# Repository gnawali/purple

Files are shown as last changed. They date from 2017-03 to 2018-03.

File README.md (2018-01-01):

# What is this repository for #

This repository contains hardware and software for building practical Visible Light Communication system. The PURPLE board is a cape that works with BeagleBone Black embedded computer. With PURPLE, one can send and receive information using visible light.

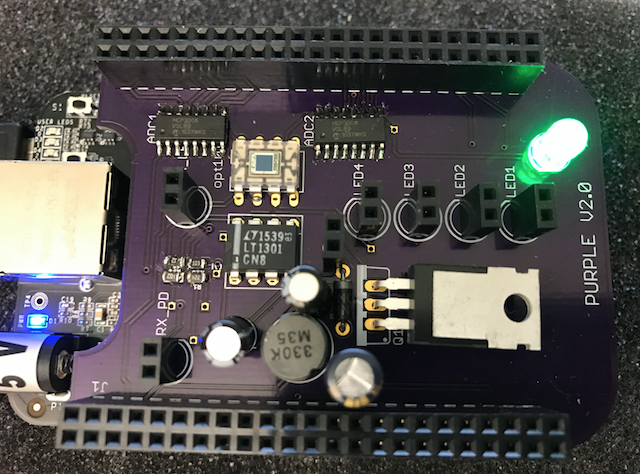
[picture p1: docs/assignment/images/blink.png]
blink


The hardware design is available in the eagle folder.

### What's included ###
* Firmware running on PRU including both transmitter and receiver
* User-space program to run on embedded Linux environment 
* Hardware schematic
* Partlist to assemble your own cape [Digi-Key](http://www.digikey.com/short/qq17qj)
* PCB ordering [OSH Park](https://oshpark.com/shared_projects/B5KA0qL4)

### Contents ###

* config/

 This directory contains all configuration files used before make.

* docs/

 This directory contains all documents and notes used as instructions and tutorials deployed in class.

* example/

 This directory contains the userspace program to send and receive msgs through light.

* firmware/

 This directory contains the binary files that's going to run on PRU

* pcb/

 This directory contains the hardware schematic and the PCB layout as well as the partlists.

* src/

 This directory contains the source file that needs to be compiled into the binary file under firmware folder.

* test/

 This directory contains the test and debugging file in user space for the PRU source code.

### How do I get set up? ###

- Summary of set up
    1. Hardware
    	- Beaglebone Black
    	- Purple Cape
    	- SD card
    	- Micro USB cable
    2. Software
	    - BBB Driver[[Windows]](https://learn.adafruit.com/ssh-to-beaglebone-black-over-usb/installing-drivers-windows)[[Mac]](https://learn.adafruit.com/ssh-to-beaglebone-black-over-usb/installing-drivers-mac)[[Linux]](https://learn.adafruit.com/ssh-to-beaglebone-black-over-usb/installing-drivers-linux)
	    - SSH[[Windows]](https://learn.adafruit.com/ssh-to-beaglebone-black-over-usb/ssh-with-windows-and-putty)[[Mac/Linux]](https://learn.adafruit.com/ssh-to-beaglebone-black-over-usb/ssh-on-mac-and-linux) 
    3. Internet Connection (optional)
	    - Ethernet Cable (Required physical access to the LAN port of your router/access point)
	    - [Wireless Dongle](https://learn.adafruit.com/setting-up-wifi-with-beaglebone-black/overview)
    
* Configuration
* Dependencies
* Deployment instructions
  1. LED installation.
  2. Photodiode installation.

### How to get started ###

Step 1: Insert SD card to BBB board. Make sure SD card has been flashed with the purple image.

Step 2: Boot Up the BBB board and connect the board to your PC/Laptop. Make sure you have successfully installed the drivers for BBB.

Step 3: SSH to the board. ssh debian@192.168.7.2

```
ssh debian@192.168.7.2
```
Step 4: When you login, Change to root.

```
sudo -s
```

Step 5: Go to purple repository.

```
cd purple
```

Step 6: Reload the pru remoteproc kernel module.

```
rmmod pru_rproc

modprobe pru_rproc

```

Step 7: Compile the code.
```
make clean
make
```
Step 8: Make sure the code got compiled succesfully.

Step 9: Start listening on incoming messages on one purple board.
```
cd example
./receive
```

Step 10: Start sending the messages on other purple board.
```
cd example
./send "hello world"
```

Step 11: Make sure the message got received correctly.

Step 12: Congratulations. You've completed this short tutorial.

### Who do I talk to? ###

* Shengrong Yin (syin@uh.edu) 
* Omprakash Gnawali (gnawali@cs.uh.edu) 

### References ###

[Exploring Beaglebone](http://exploringbeaglebone.com/chapter13/)

[PRU-ICSS](http://processors.wiki.ti.com/index.php/PRU-ICSS)

[PRU-software-support-package](https://git.ti.com/pru-software-support-package)

[spruhv7a](http://www.ti.com/lit/ug/spruhv7a/spruhv7a.pdf)

[arduino VLC](https://github.com/jpiat/arduino)

[PRU mailing list](https://groups.google.com/forum/#!forum/beagleboard)

[BeagleScope](https://github.com/ZeekHuge/BeagleScope)

[PRUDAQ](https://github.com/google/prudaq/wiki)

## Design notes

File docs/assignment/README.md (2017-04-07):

# OpenVLC 1.0 Get Started
This is to introduce the embedded visible light communication system based on BeagleBone Black (Rev. C) [BBB](http://beagleboard.org/project/OpenVLC/). 

## What do you need to get started
* 2 x [BBB Rev.C ](https://beagleboard.org/black) 
* 2 x [OpenVLC Cape](http://nsl.cs.uh.edu/~syin/openvlc/cape1.png)
* 2 x [mini USB cable](http://nsl.cs.uh.edu/~syin/openvlc/miniUSB.jpg)
* 2 x [LED (Type 1)](http://www.vishay.com/docs/83178/tlcr5800.pdf)
* 2 x [LED (Type 2)]
* 2 x [Power Supply](http://elinux.org/images/7/72/DC_Supply.jpg).

## Hardware Assembly
1. Attach the cape on top of BBB.
2. Attach LED on the pinout of the cape. See the [instructions](http://nsl.cs.uh.edu/~syin/openvlc/led_installation.pdf)
3. Power up the board.
4. Connect the mini USB cable to your PC/Desktop USB port.

## Software Preparation
1. Installing the image:
   * **OpenVLC image**: 
   * Download the [image](https://drive.google.com/file/d/0BwGT2J3dvAfNOEVibS1KQ2d5MGc/view)
   * Install the image on a SD card. You can following the [Raspberry Pi example](https://www.raspberrypi.org/documentation/installation/installing-images/)
   * Insert the SD card to BBB and boot the OS.
   * Install the [header file](https://drive.google.com/file/d/0BwGT2J3dvAfNcVljMTFUU2phQmc/view?usp=sharing) on BBB.
     For this, you can ssh to the board
`ssh machinekit@192.168.7.2` and type
`dpkg -i linux-headers-3.8.13xenomai-bone53_1.0cross_armhf.deb`
   * Download the openvlc source code and compile it.
2. Check on your PC/Desktop to see whether you have USB connections after you assembled all hardware.
   * **For Mac Users**: Type `option` + `space` key in your keyboard to open network preference, you will observe all operating connections. Click on the BeagleBone Black connection to see the IP address. Normally, this would be `192.168.7.1`. Once you confirmed with IP, you can connect to the board via SSH. 
   * **For Linux Users**: Open Terminal, and type `ifconfig` to see available network connections. You will observe the 
USB connection with IP address of `192.168.7.1`. Connect to the board via SSH.
   * **For Windows Users**:  First, you need to install the BeagleBone [USB drivers](http://beagleboard.org/static/Drivers/Windows/BONE_D64.exe) for windows. Before you do that, you have to disable driver signature verification on 64-Bit Windows 8 or 10 so that you can install the USB driver which is unsigned. To disable driver signature verification, please follow option 2 in this [link](http://www.howtogeek.com/167723/how-to-disable-driver-signature-verification-on-64-bit-windows-8.1-so-that-you-can-install-unsigned-drivers/). Once you install the USB driver successfully, you can open `Command Line Tools` and type `ipconfig`. You will notice a IP which is `192.168.7.1` from
the result. This shows the USB driver is successfully installed. 
Second, download [Putty](http://www.chiark.greenend.org.uk/~sgtatham/putty/download.html) and connect from Windows to the BeagleBone board using Putty. 

## Connecting to the BeagleBone Board (SSH)
   * **For Mac and Linux Users**: By default, the OS should already have SSH installed. So you can open terminal and type the following command  `ssh machinekit@192.168.7.2`. The default password is `machinekit`.
   * **For Windows Users**: You need to configure Putty using the IP address `192.168.7.2`. You can following this [tutorial](https://mediatemple.net/community/products/dv/204404604/using-ssh-in-putty-) to configure the SSH connection in Putty.

## Data Transmission Configuration.
Once you are able to access to the BBB via SSH.  

`sudo -s #change to root`   
`cd openvlc1.0 # go to the folder`  
`./bat_client.sh # insert the openvlc kernel module and configure it to be TX`  
`./ipert_client.sh # run iperf tool to start transmitting data throught the visible light channel`  

## Data Reception Configuration.
Once you are able to access to the BBB via SSH.  
`sudo -s # change to root`  
`cd openvlc1.0 # go to the folder`  
`./bat_server.sh # insert the openvlc kernel module and configure it to be RX`
`./iperf_server.sh # run iperf tool to start receiving data throught the visible light channel`

## Visible Light Communication Verification
From the iperf server terminal, you will observe the following measurement result.

As we can see from the iperf measurement result, the visible light communication link is established so that
we can observe the loss ratio and the round-trip time estimation (RTT).

Still so excited, let's start to work on some tasks that can help you learn how the system is implemented and what improvements we can help to contribute.

# Homework 1 (How to compile C file in Embedded Linux Environment)

- Objective:  
  - You will learn how to compile a file in Linux Environment.
  - You will learn how to use networking tools in Linux Environment, such as iperf, nc e.t.c.

- Instructions:  
   - In openVLC 1.0, we have provided an example file for you to get started, you can type the following command
to go to the example folder, which is `openvlc1.0`.  
`cd openvlc1.0`  
Here, you will find the source files that are used to create the kernel module. Normally, the kernel module has
a filetype that is `***.ko`. And you can load this module into the kernel to drive the VLC transceivers. 
It is similar when you plug in a WIFI USB dongle. Kernel driver for this particular WIFI USB dongle will load firmware 
into the MCU of the device and the USB device will start to transmit or receive data. Here, the VLC transceivers was 
managed by only the kernel module with no firmware running on external MCU.
To compile the source file into the kernel module, you just need to type  
`make`   
Linux will automatically compile the source file into the vlc.ko.  
Once you have the `vlc.ko` module, you need to load it into kernel. We wrote the script -`bat_client.sh` to help you load 
ther kernel with default configurations. But currently, the system is half-duplex meaning you have to configure the transceiver as either TX or RX. Let's assume we configure the first device as TX, we need to type  
`./bat_client.sh`.  
Now we are able to send data using the VLC transceiver that has been configured as the TX by typing  
`iperf_client.sh`  
You will observe the LED blinking as the indication for data transmission.  
   - In this homework, you need to repeat the procedure from the descriptions and submit a screenshot with the data analytics you received from the iperf server result.  

# Homework 2 (How to write a new modulation/demodulation for openVLC)
- Objective:
   - You will learn how data was transmitted from a human readable message to the binary code that are sent in physical layer. 
   - You will learn Linux Kernel Programming by modifying the kernel source file.
   - You will learn basic modulation and demodulation techniques for data communication.
- Instructions:  
   - We have provided you a C file and a Makefile to help you get started. Check this [repository](https://github.com/yinshengrong/vlc_lab1) to be prepared with the tasks. This lab will help you understand the basic 
kernel programming techniques. It is sending a fixed number of bytes from Kernel by controlling the blinking frequency of
the LED. It is modulating bit ONE and ZERO with different frequency. The frequency for bit ONE is 3 kHz, bit ZERO is 1.5 kHz. By blinking the LED using these two frequencies, the Binary Frequency Shift Keying Modulation is established.  
   - In this homework, you need to modify this BFSK modulation into an [On and Off Keying Modulation with Manchester Coding](https://en.wikipedia.org/wiki/On-off_keying). You should be able to modulate bit ZERO using the HIGH-LOW trigger and modulate bit ONE using the LOW-HIGH trigger or vice versa. 

# Homework 3 (Wireshark)

# Homework 4 (Socket programming on VLC)

# Homework 5 (ARM and PRU assembly)

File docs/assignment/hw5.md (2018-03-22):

# Blink LED with Programmable Realtime Unit 
This is to introduce the embedded visible light communication system based on BeagleBone Black (Rev. C). 

## What do you need to get started
* 2 x [BBB Rev.C ](https://beagleboard.org/black) 
* 2 x [Purple VLC Cape](https://github.com/gnawali/purple/blob/master/docs/assignment/images/blink.png)
* 2 x [mini USB cable](http://nsl.cs.uh.edu/~syin/openvlc/miniUSB.jpg)
* 2 x [LED (Type 1)](http://www.vishay.com/docs/83178/tlcr5800.pdf)

## Hardware Assembly
1. Attach the cape on top of BBB.
2. Attach LED on the pinout of the cape. See the [instructions](http://nsl.cs.uh.edu/~syin/openvlc/led_installation.pdf)
3. Power up the board.
4. Connect the mini USB cable to your PC/Desktop USB port.

## Software Preparation
1. Installing the image:
   - **Purple image**: 
   - Download the [image](https://debian.beagleboard.org/images/bone-debian-8.6-lxqt-4gb-armhf-2016-11-06-4gb.img.xz)
   * After downloading the image, you need 7-zip to extract the img file. You can first download [7-zip](http://www.7-zip.org/download.html). Then right click on the image file with the 7zip option to extract here.
   * Install the image (.img file) on a micro SD card. You can following the [Raspberry Pi example](https://www.raspberrypi.org/documentation/installation/installing-images/). If you are using Windows, you can download [Etcher](https://etcher.io/) and install the application, and write the .img file to SD card. You may need a [USB-to-microSD adaptor](https://www.amazon.com/Sabrent-SuperSpeed-Windows-Certain-Android/dp/B00OJ5WBUE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) if the computer you are using does not have the SD card slot. It will approximately take 10-20 minutes to write the image to your microSD card depending on the speed of the CPU that is running on your computer.
   * Insert the SD card to BBB and plug in BBB board on your computer via the provided USB cable.
   * If the OS running on your computer in Windows 10, you need to get a BBB driver for signed signature to be installed on your windows. You can download [this one](http://www.1-2-3-4-5-6.net/beaglebone/black/BONE_D64_signed.zip).
   * Download [Putty](http://www.chiark.greenend.org.uk/~sgtatham/putty/download.html) and connect from Windows to the BeagleBone board using Putty. 
   * Connect to the BBB board via ssh.
     `ssh debian@192.168.7.2`
   * After you logged in to the board, you can following [this link](http://elinux.org/EBC_Exercise_30_PRU_via_remoteproc_and_RPMsg) to load PRU kernel modules. To sum up, it is really important for you to follow the sequence.
   * In order to make things easier, we type all commands using root. To change the user to root, simply type the following command in a
   terminal.
   
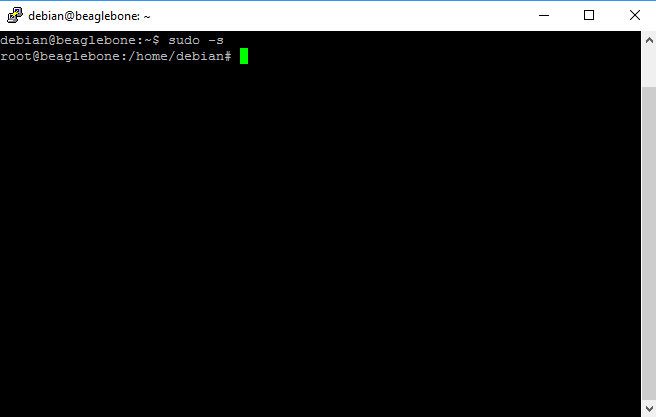
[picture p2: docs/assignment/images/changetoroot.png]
teminal<

   ```
   sudo -s
   ```
2. Enabling PRU module via Remoteproc framework:
   * **Check version**: we need to make sure the board version is larger than 4.4.12-ti-r32 or the following instructions will be   invalid.
   
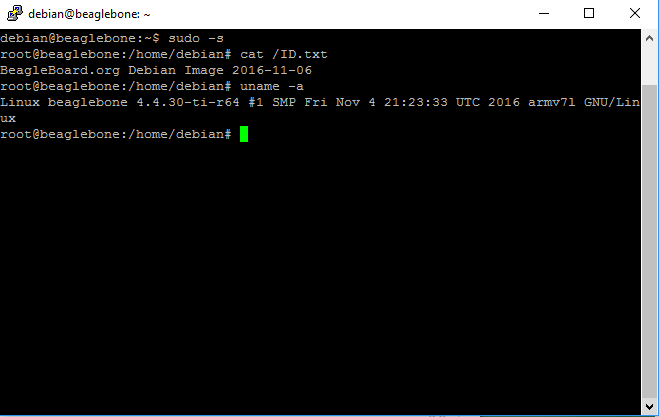
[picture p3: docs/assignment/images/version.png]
version<

   ```
   cat ./ID.txt
   uname -a
   ```
   * **Disable the HDMI**: The BBB provide multiplexing for the GPIOs, both PRU and HDMI will share the same GPIOs, so we have to disable the HDMI before we enable the PRU. How do we know whether the HDMI is disabled:
   
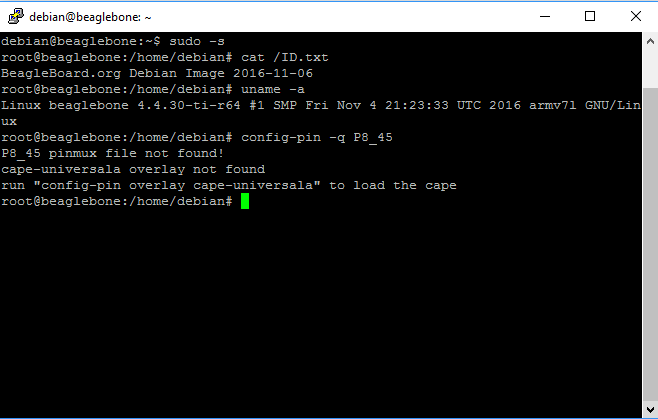
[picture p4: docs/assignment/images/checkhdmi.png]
checkHDMI<

   ```
   config-pin -q P8_45
   ```
   If the message was shown up in the terminal, we need to disable the HDMI. Open the `/boot/uEnv.txt`.
   
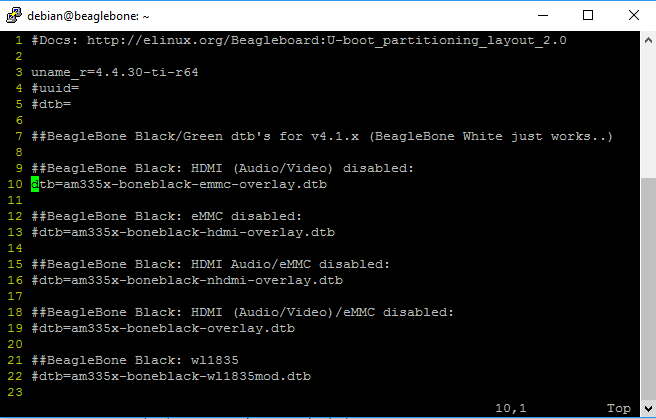
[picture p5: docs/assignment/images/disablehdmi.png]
disableHDMI<

   ```
   nano /boot/uEnv.txt
   ```
   After uncommenting # in line number 10, we save the file and reboot.
   
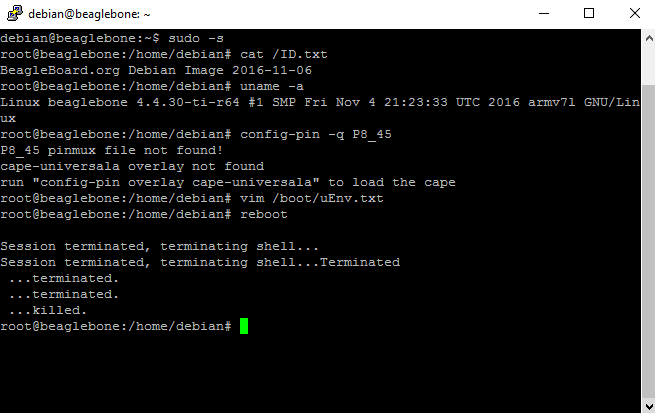
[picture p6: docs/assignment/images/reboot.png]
root<

   ```
   reboot
   ```
   Logging into the board again and check whether hdmi is disable:
   
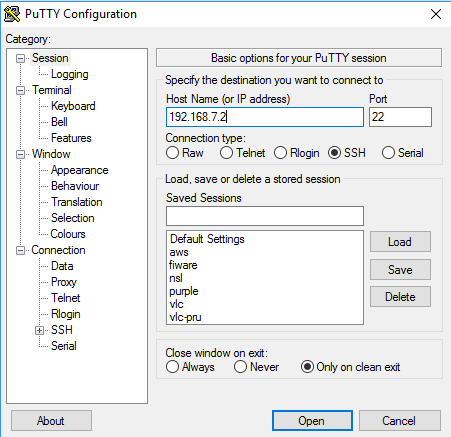
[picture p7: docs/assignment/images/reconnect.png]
reconnect<

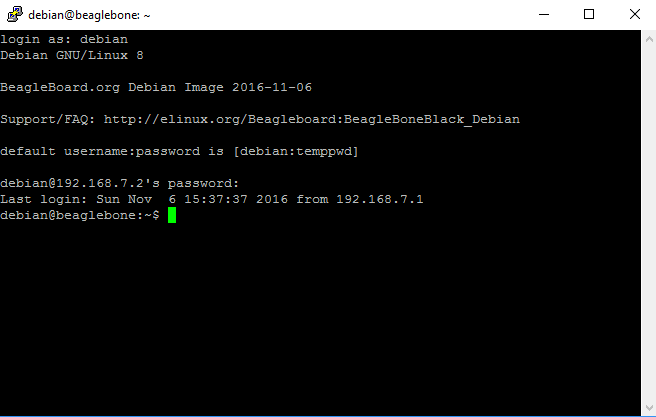
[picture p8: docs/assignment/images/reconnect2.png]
reconnect2<


   Now we can confirm that the HDMI is disabled.
   * **Setting up the PRU compiler**: The pru compiler should be installed by default.
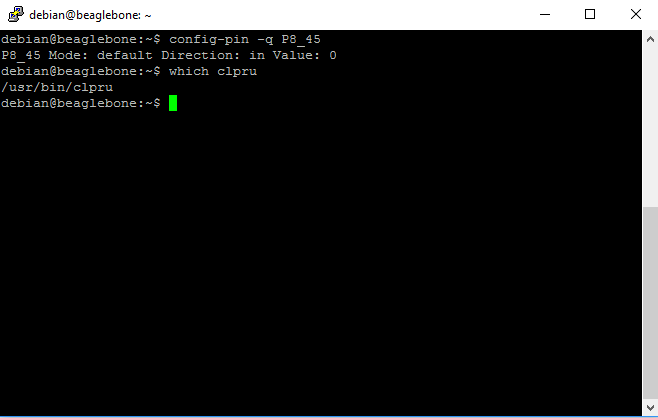
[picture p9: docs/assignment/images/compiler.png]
compiler<

   ```
   config-pin -q P8_45
   which clpru
   ```
   We also need to set up the environment variable to make sure the Makefile in the following is makable. We want to put the environment variable in the `.bashrc` file so that the environment variable will be always valid. To do that, we open the `.bashrc` file under `/`.
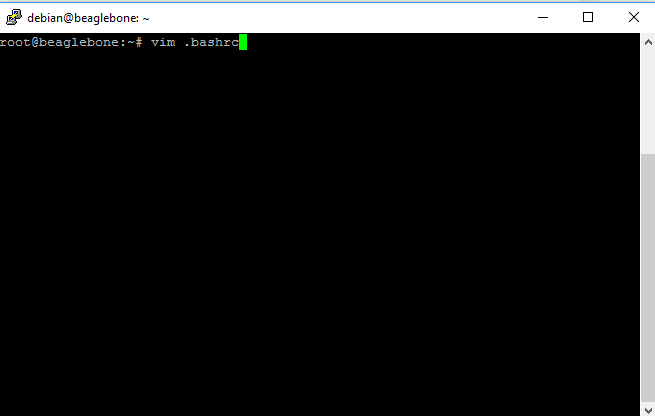
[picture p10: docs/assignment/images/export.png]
export<


   ```
   nano .bashrc
   ```
   Then we add the following two lines at the bottom of the file.
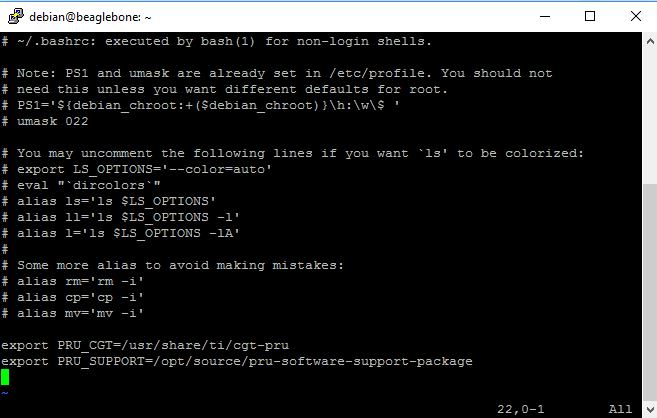
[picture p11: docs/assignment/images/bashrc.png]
bashrc<

   ```
   export PRU_CGT=/usr/share/ti/cgt-pru
   export PRU_SUPPORT=/opt/source/pru-software-support-package
   ```
   Once we added the environment variable, we reenter the shell via the following commands.
verifybash<
   ```
   exit
   sudo -s
   $PRU_CGT
   ```
   Then we create some hard link to ensure the make system can find right library under the right path.
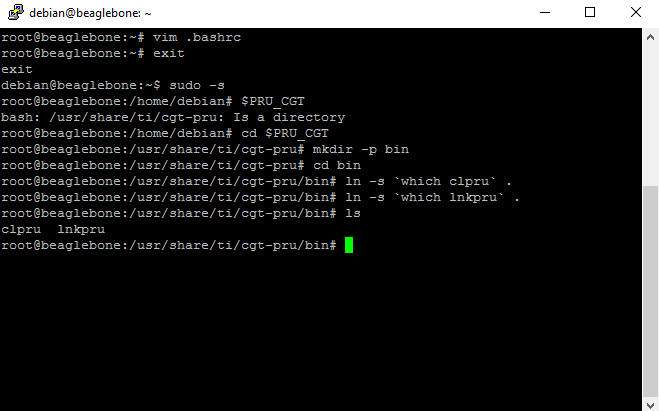
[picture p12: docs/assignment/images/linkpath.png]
linkpath<

   ```
   cd $PRU_CGT
   mkdir -p bin
   cd bin
   ln -s `which clpru` .
   ln -s `which lnkpru` .
   ```
   
   * **Enabling remoteproc**: check whether remoteproc is already enabled.\
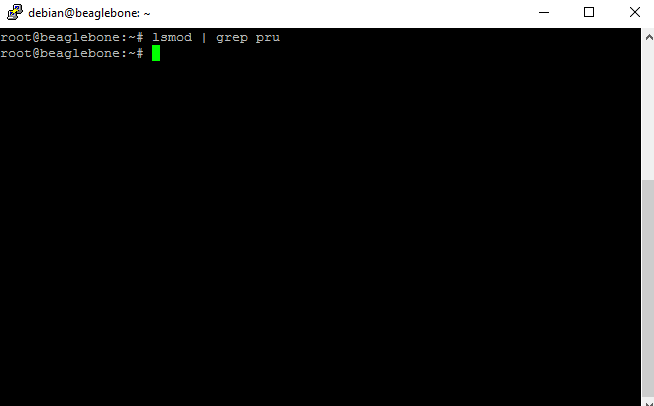
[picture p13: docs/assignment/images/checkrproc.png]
checkrproc<

   ```
   lsmod | grep pru
   ```
   Then we need to edit the device tree
   ```
   cd /opt/source/dtb-4.4-ti
   nano src/arm/am335x-boneblack-emmc-overlay.dts
   ```
   and uncomment the following line
   ```
   /* #include "am33xx-pruss-rproc.dtsi" */ 
   ```
   to
   ```
   #include "am33xx-pruss-rproc.dtsi"
   ```
   Then
   ```
   make
   make install
   ```
   Then blacklist and reboot
   ```
   echo "blacklist uio_pruss" > /etc/modprobe.d/pruss-blacklist.conf
   reboot
   ```
   Check the remoteproc module again 
   ```
   lsmod | grep pru
   ```
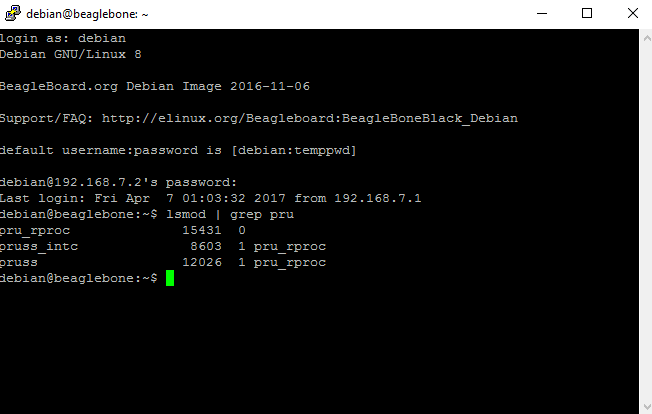
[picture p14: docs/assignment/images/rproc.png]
rproc<

   * ** Downloading BeagleScope Examples **: You need to connect the Ethenert cable to the BBB to make sure it is connected.
   ```
   ifconfig
   ```
 	Then change the time on BBB so that the make will not have the problem of clock skew. Make sure you are running as root.
   ```
   sudo -s
   dpkg-reconfigure tzdata (select your timezone)
   ```
   Create a folder to place all the examples.
   ```
   mkdir pru
   ```
   Download the repository:
   ```
   git clone  https://github.com/ZeekHuge/BeagleScope.git
   ```
   Create a symbolic link for the blink source code:
   ```
   ln -s `path to the blink source code` blink
   ```
   Go to the blink folder:
   ```
   cd  blink
   ```
   Now blink the LED wired to P8_45 (The script will configure and compile the program):
   ```
   ./deploy.sh
   ```
   You need to hit enter to make the program compile. After that, the onboard RGB led will be blinked every 1 second.
blink<
   
2. Check on your PC/Desktop to see whether you have USB connections after you assembled all hardware.
   * **For Mac Users**: Type `option` + `space` key in your keyboard to open network preference, you will observe all operating connections. Click on the BeagleBone Black connection to see the IP address. Normally, this would be `192.168.7.1`. Once you confirmed with IP, you can connect to the board via SSH. 
   * **For Linux Users**: Open Terminal, and type `ifconfig` to see available network connections. You will observe the 
USB connection with IP address of `192.168.7.1`. Connect to the board via SSH.
   * **For Windows Users**:  First, you need to install the BeagleBone [USB drivers](http://beagleboard.org/static/Drivers/Windows/BONE_D64.exe) for windows. Before you do that, you have to disable driver signature verification on 64-Bit Windows 8 or 10 so that you can install the USB driver which is unsigned. To disable driver signature verification, please follow option 2 in this [link](http://www.howtogeek.com/167723/how-to-disable-driver-signature-verification-on-64-bit-windows-8.1-so-that-you-can-install-unsigned-drivers/). Once you install the USB driver successfully, you can open `Command Line Tools` and type `ipconfig`. You will notice a IP which is `192.168.7.1` from
the result. This shows the USB driver is successfully installed. 

## Connecting to the BeagleBone Board (SSH)
   * **For Mac and Linux Users**: By default, the OS should already have SSH installed. So you can open terminal and type the following command  `ssh machinekit@192.168.7.2`. The default password is `machinekit`.
   * **For Windows Users**: You need to configure Putty using the IP address `192.168.7.2`. You can following this [tutorial](https://mediatemple.net/community/products/dv/204404604/using-ssh-in-putty-) to configure the SSH connection in Putty.

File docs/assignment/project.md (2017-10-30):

# Project Description (tentative).
In this project, students are going to build a simple LED-to-Photodiode
communication system that can transmit "hello world" message from the
transmitter to the receiver. The overall data flow for this project is shown in
the following figure.
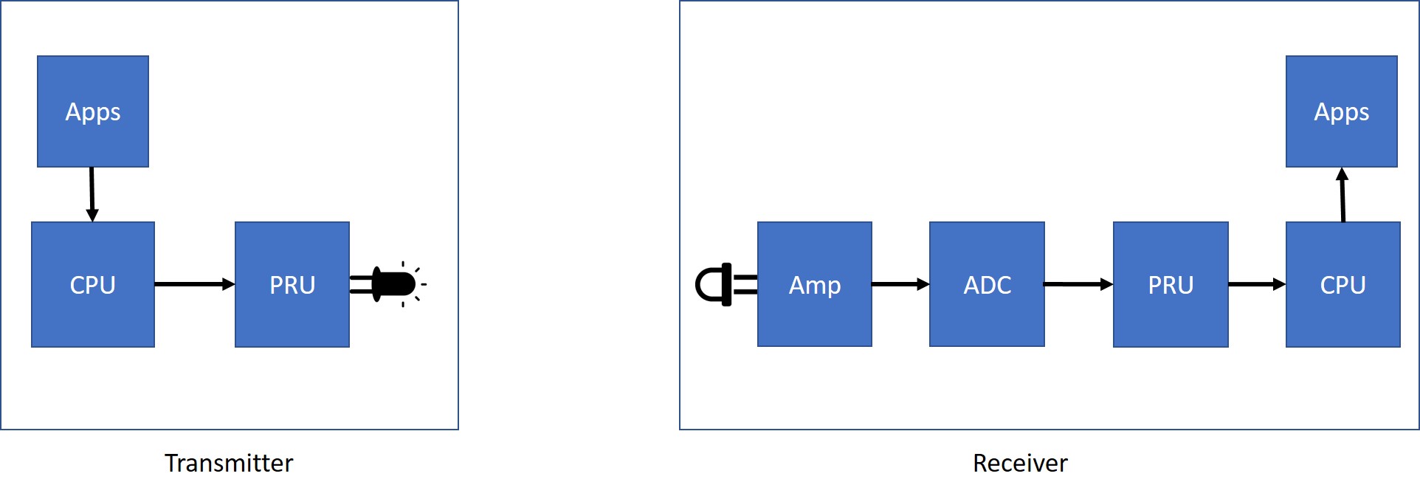
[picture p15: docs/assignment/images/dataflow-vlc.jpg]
dataflow=

* Apps: The apps is a userspace program that needs to send some information to
  PRU so that PRU can control the LED to send the uplayer information. For
example, the userspace program in this project needs to read a file and send
the file content to PRU. The file content is "hello world".
* CPU: The CPU is 1GHz ARM core. It runs a debian Linux and it provides IPC
  mechanism to facilitate the communication between userspace program and
kernel. So that it forwards the message from userspace to PRU with the help of
kernel drivers. In this project, we will apply the latest framework suggested
by TI to implement the messaging forwarding.
* PRU: The PRU is another processor with a speed of 200MHz. TI has released an
  open-source C-compiler for this processor such that developers can write C
code under Linux to be running on PRU. In this project, we'll provide example C
code to modulate the forwarded message by controlled LED built on the
transmitter.
* Amp: This is a transimpedence amplifier that is used to amplify the voltage
  signal from the photodiode. It has lots of electronics. But the board you'll
working on has the built-in amplifier such that you don't need to worry about
all the electronics detail.
* ADC: This will convert the amplified signal from analog to digital so that
  PRU recognize the bits. You may need to understand how ADC and PRU
communication in order to understand the conversion process. But don't worry,
We'll teach you how the ADC work and how the PRU receive the data from the ADC
step-by-step. You may need to worry about how to decode the message from
noises. 
* PRU: Well, it will be basically a lot of data coming out from the ADC, and
  the PRU needs to recognize the correct byte. For this part, you need to
design the packet encoding mechanism. The good thing is there are tons of
tutorials online teaching you how to encode the packet. Actually, it should be frame since we are discussing the data communication in PHY layer. But the principles are the same as all you need to care is how much payload you should
allocate for a packet/frame. What should be the packet/frame header? Do we need
some synchronization byte or not. Do we also need the meta bytes at the end of
the packet/frame? Is it also a good idea to add the packet/frame length?
* Apps: In the apps of the receiver, your userspace program will simply receive
  the bytes from PRU and display on the terminal with ASCII format.  
# What you will learn from this project.
* Students will learn practical skills working under Linux Environment.
* Students will learn basic Linux commands.
* Students will learn how practical wireless communication system works.
* Students will learn basic modulation technique.
* Students will learn how to improve optic communication performance.
* Students will learn how to communicate between kernel and userspace.
* Students will learn how to encode and decode packets in PHY layer.
* Students will learn how to compile and debug Assembly/C program under Linux.
# What do you need to do in the project.
1. Modify a C program that can be successfully compiled and run in PRU such that the PRU will run this program to send the message 
with the onboard LED.
2. Modify a C program that can be successfully compiled and run in PRU such that the PRU will run this program to receive the message
with onboard Photodiode.
3. Write a C program that is similar to previous examples to adapt the packet decoding under various number of LEDs (optional).

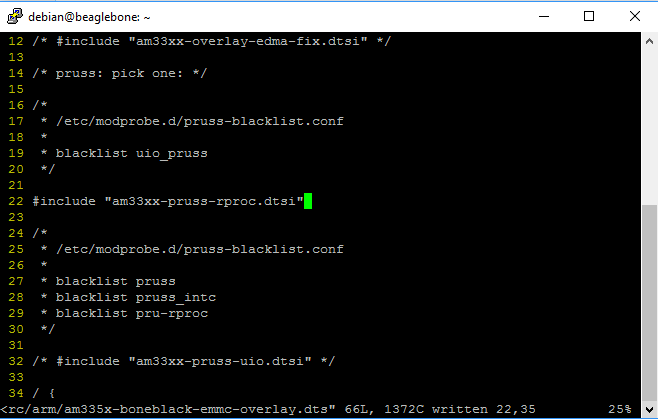
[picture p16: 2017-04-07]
docs/assignment/images/uncommentrproc.png

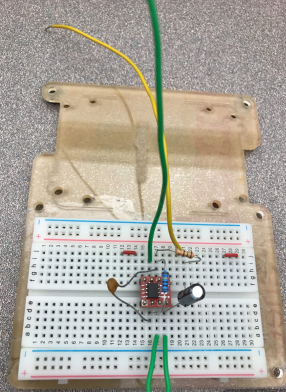
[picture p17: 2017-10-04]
docs/assignment/images/Capture02.PNG

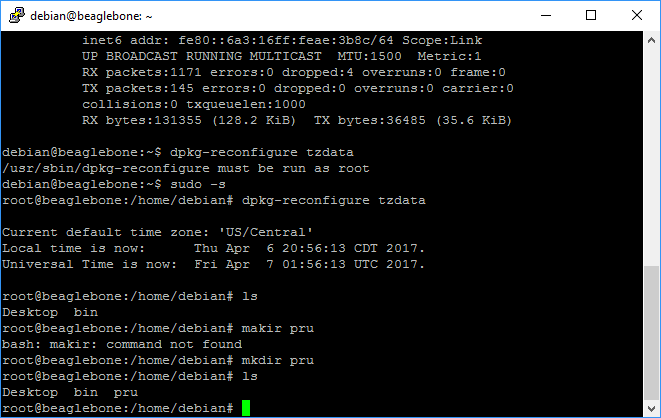
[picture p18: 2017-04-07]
docs/assignment/images/mkdirpru.png

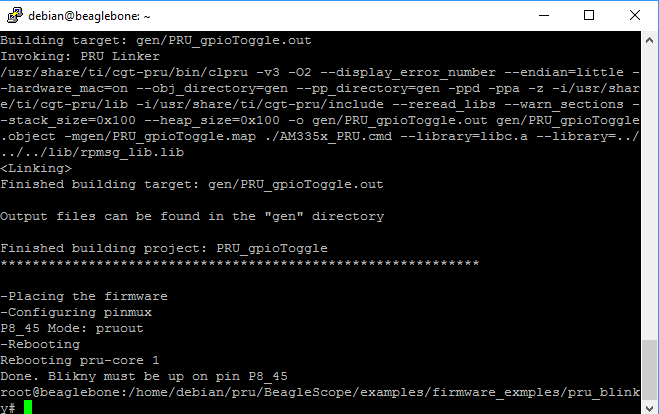
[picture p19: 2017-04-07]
docs/assignment/images/deploy.png

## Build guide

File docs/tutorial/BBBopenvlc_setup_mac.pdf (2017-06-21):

OPEN VLC
INSTALLING DEBIAN (MACHINEKIT) OPERATING SYSTEM TO EMPTY SD CARD Guide for MAC OS users.

This document follows the instructions to do the Experimental setup for OPENVLC. Similar procedure is shown at openvlc.org web page: http://www.openvlc.org/openvlc.html.

STEPS

1. Download Debian image, current link is https://drive.google.com/file/d/0BwGT2J3dvAfNOEVibS1KQ2d5MGc/view Remove the. xz extension and keep it with .ISO
Save it, we will use it in the next steps.
2. Format the SD card, SDFormatter can be used to do this.
Download it at: https://www.sdcard.org/downloads/formatter_4/eula_mac/

The interface should look something like this.

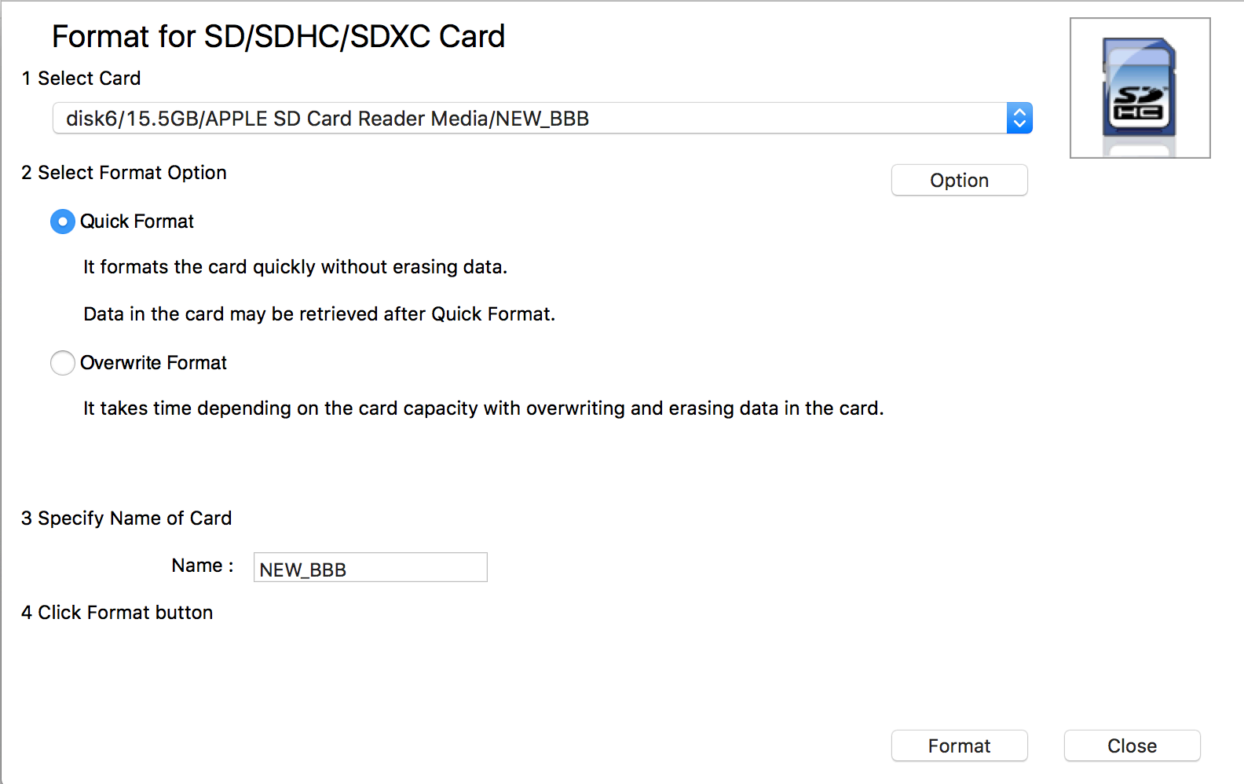
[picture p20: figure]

Select your card and click Format. It should take a few seconds.

3. Now it’s time to burn the image into the SD, for simplicity, download Etcher: https://etcher.io/ . Select the Debian ISO file and your SD card.

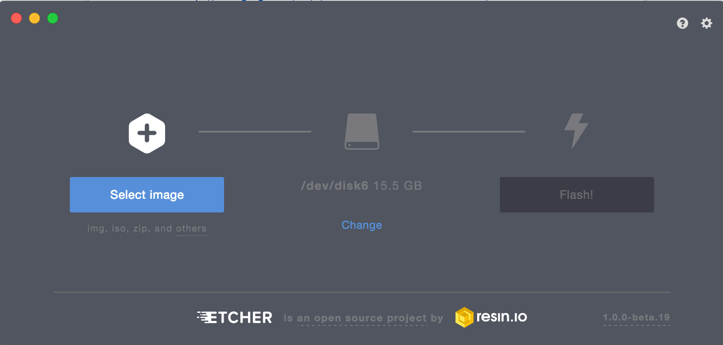
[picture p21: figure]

Depending on the size of the SD cards this could take up to 20 minutes.

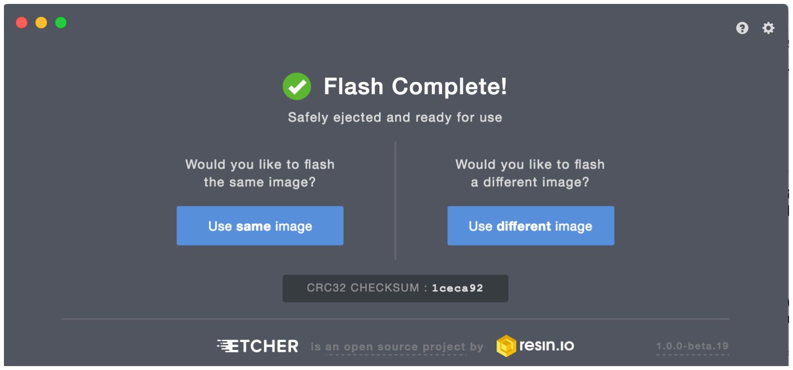
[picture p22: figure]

Remove and insert the SD card. You should now see BEAGLE_BONE in your devices

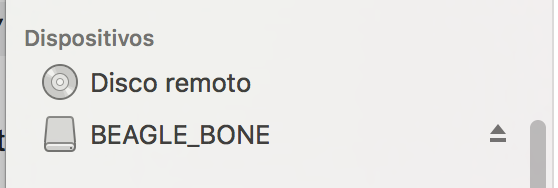
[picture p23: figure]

4. INSERT the SD card into the Beagle Bone Board and plug it in via the USB cable to the computer, give it some time to recognize the board. At this moment, the default IP address for the BBB it 192.168.7.2. Now we will ssh the BBB but before we need to install two drivers.

Open a browser, then type the IP before mentioned, you should see this:

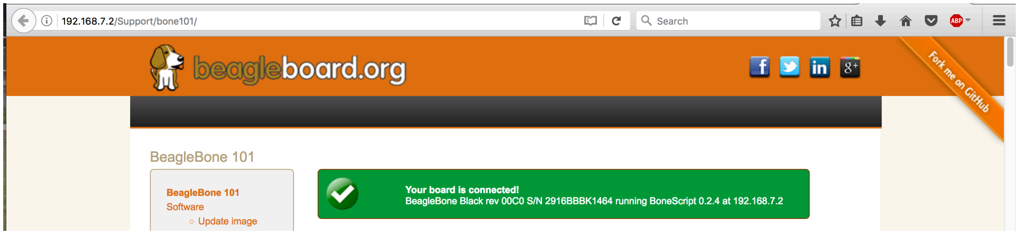
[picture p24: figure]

If you get that green message, then we are good to go, if not, something was made wrong in the previous steps.

Divers for MAC are located in the get started section in the beagleboard.org page, goto: https://beagleboard.org/getting-started#step2

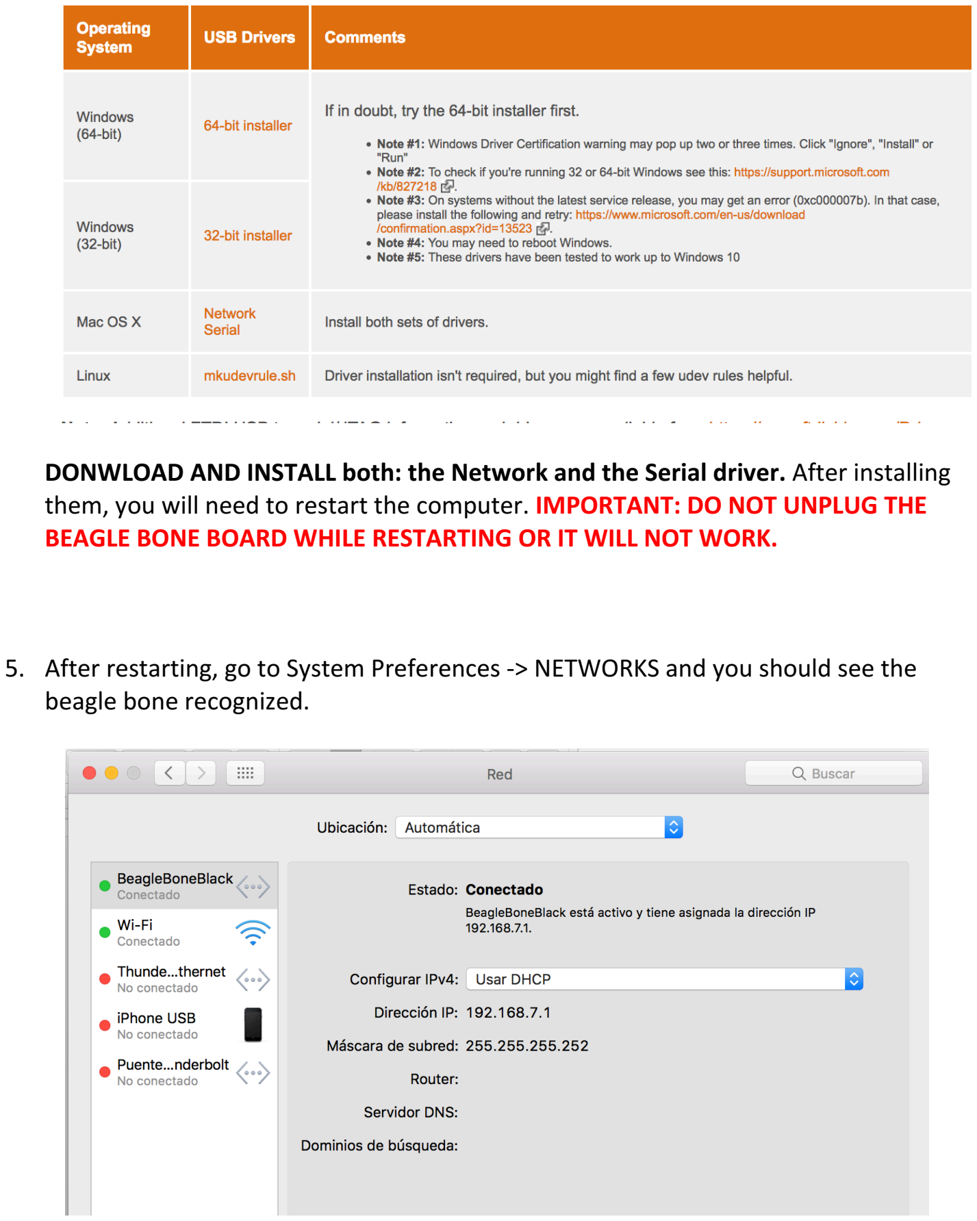
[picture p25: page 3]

DONWLOAD AND INSTALL both: the Network and the Serial driver. After installing them, you will need to restart the computer. IMPORTANT: DO NOT UNPLUG THE BEAGLE BONE BOARD WHILE RESTARTING OR IT WILL NOT WORK.

5. After restarting, go to System Preferences -> NETWORKS and you should see the beagle bone recognized.

6. Time to SSH to the BBB, open a Terminal window, type the command:

ssh machinekit@192.168.7.2 , then yes

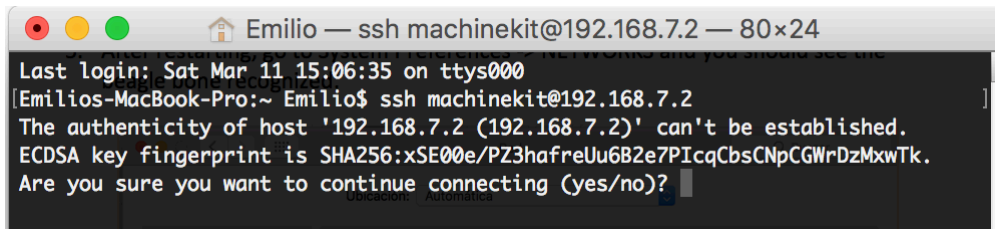
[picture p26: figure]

It will ask for a PASSWORD: it it the same as the user: machinekit

After that, you’ll be inside the board, try ls –l to see the folders.

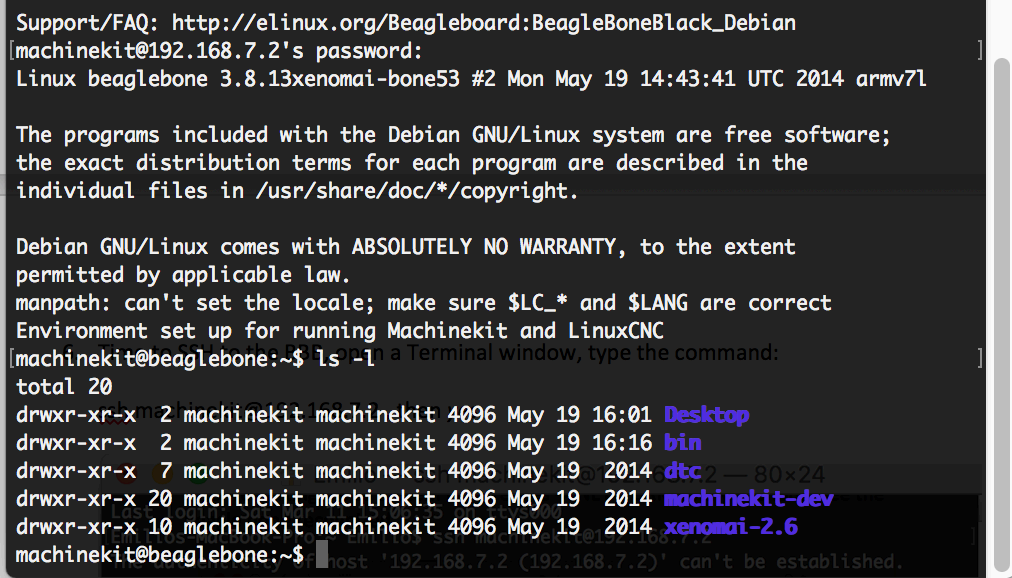
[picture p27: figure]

## HERE IS WHEN THE FUN BEGINS!!!!!

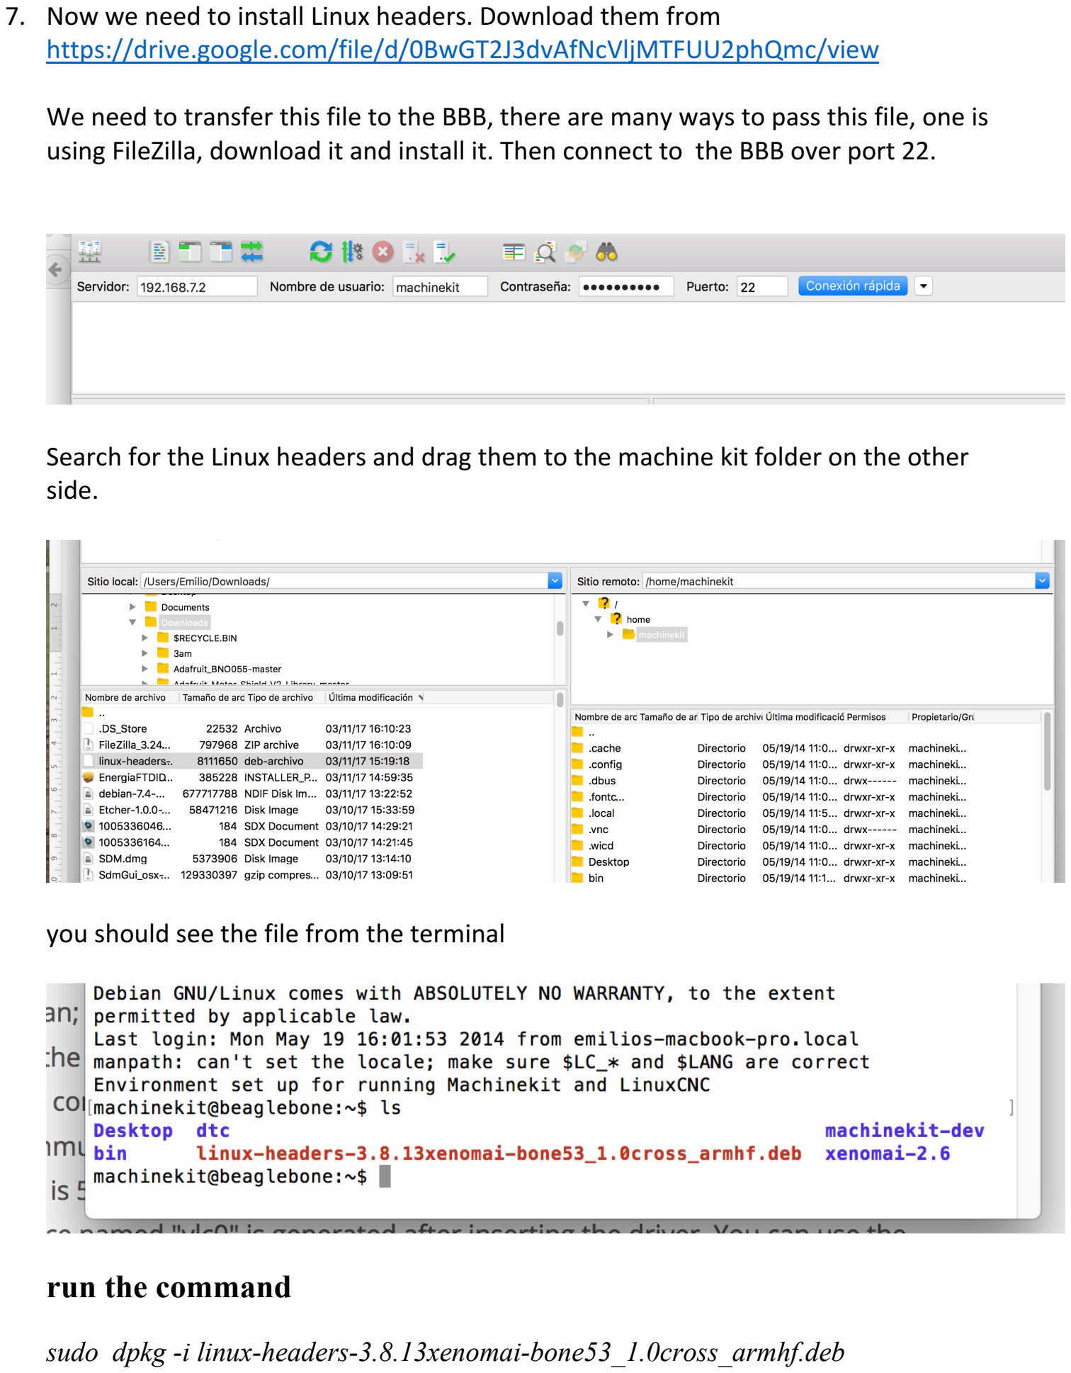
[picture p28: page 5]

7. Now we need to install Linux headers. Download them from https://drive.google.com/file/d/0BwGT2J3dvAfNcVljMTFUU2phQmc/view

We need to transfer this file to the BBB, there are many ways to pass this file, one is using FileZilla, download it and install it. Then connect to the BBB over port 22.

Search for the Linux headers and drag them to the machine kit folder on the other side.

you should see the file from the terminal

run the command

sudo dpkg -i linux-headers-3.8.13xenomai-bone53_1.0cross_armhf.deb

8. Now, download most recent version of openvlc from its github page, this is the link: https://github.com/openvlc/openvlc
Since at this time your BBB won’t have internet access, download and unzip it in the computer and then pass the folder using FileZilla as in the step before.
9. Move to the openvlc folder, cd openvlc-maste. You should see the next files, makefiles simplify life, I’m I wrong? Now just type make
10. We have finished the setup! You can run the load_driver_server or load_driver_client to set up the new interface for the BBB.

Now, the cape board allow two types of transmission and reception. By default it could be configured to use the HIGH powe LED and the PhotoDiode. We will be using the LED’s to do this, therefor we need to modify the load_driver files.

For both files and both lines change the echo > 1 to echo > 0. You should leave it as the image. Remember, both files and both lines.

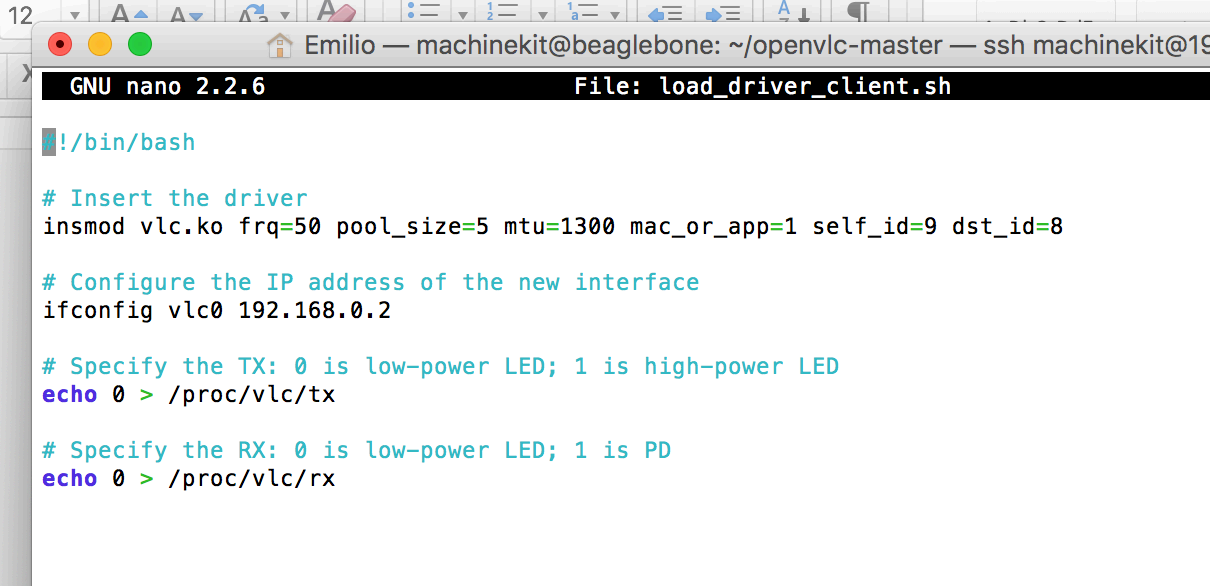
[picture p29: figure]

Modify the file, and run the script, (LED will turn off), now you will have the new interface, you can see it using ifconfig.

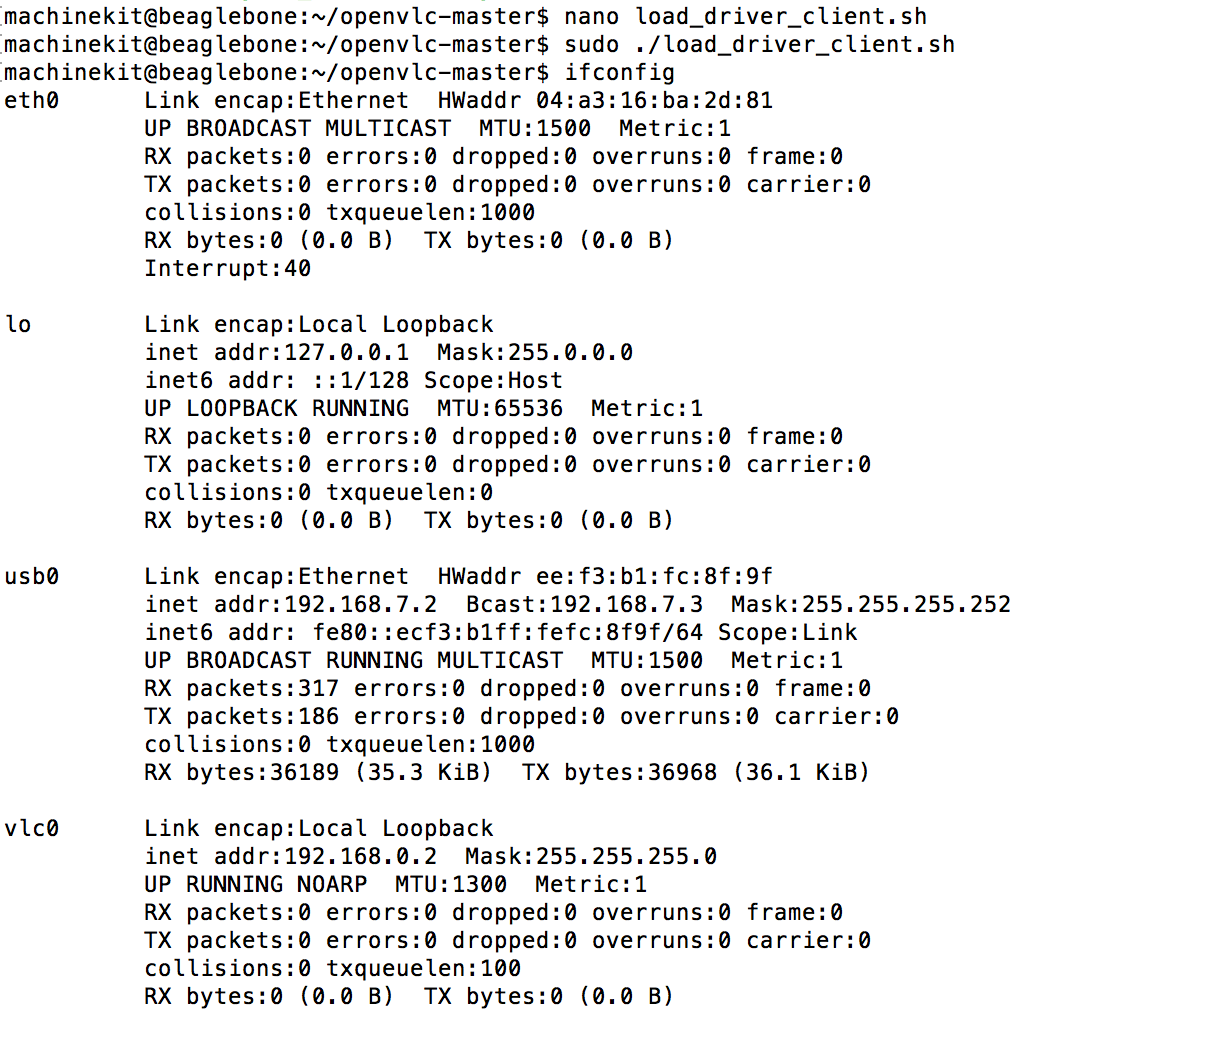
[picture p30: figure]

Once those files are modified, and the driver is loaded, try the ping command. Ping 192.168.0.1

The LED will start blinking !!!

Note: if you try to ping something that is not in you LAN, you will get the message:
connect: Network is unreachable

So just ping something inside of the VLC interface network. Try 192.168.0.3. If you have done everything ok the LED will for sure blink!

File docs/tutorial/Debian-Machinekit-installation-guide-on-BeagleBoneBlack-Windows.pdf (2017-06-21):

### Installation Guide for Debian machinekit ISO image on the Beaglebone Black - Windows

This guide intends to explain step-by-step how to write an ISO image to a SD card to use it on a Beaglebone Black board (BBB). The Operating System used to carry out this task is Windows 10. The official information is posted on the web page of the project: http://www.openvlc.org/openvlc.html. Before you start, make sure you have a stable Internet connection because you will need to download some software to complete the steps.

### Step-by-step Installation

1) Download the Debian machinekit image
To download the image follow this link: https://drive.google.com/file/d/0BwGT2J3dvAfNOEVibS1KQ2d5MGc/view.
When the download is complete modify the name of the file. Change it from .img.xz to .img.
2) Format the SD card
https://www.sdcard.org/downloads/formatter_4/

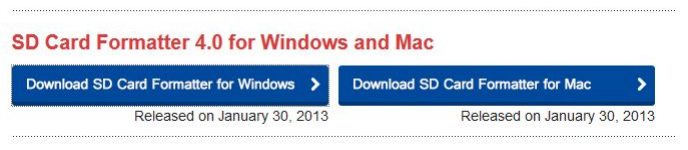
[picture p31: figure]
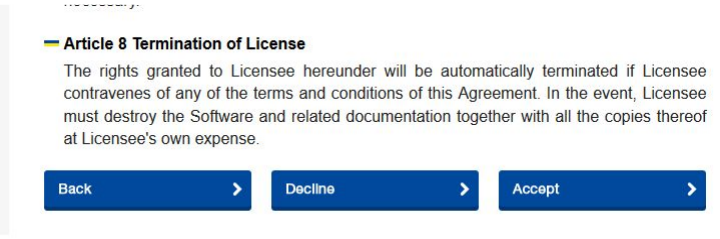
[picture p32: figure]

When you click accept the download should start. Extract the files from the .zip folder and you will find the .exe file. Run it and the installation window will prompt in order to install SD Card Formatter.

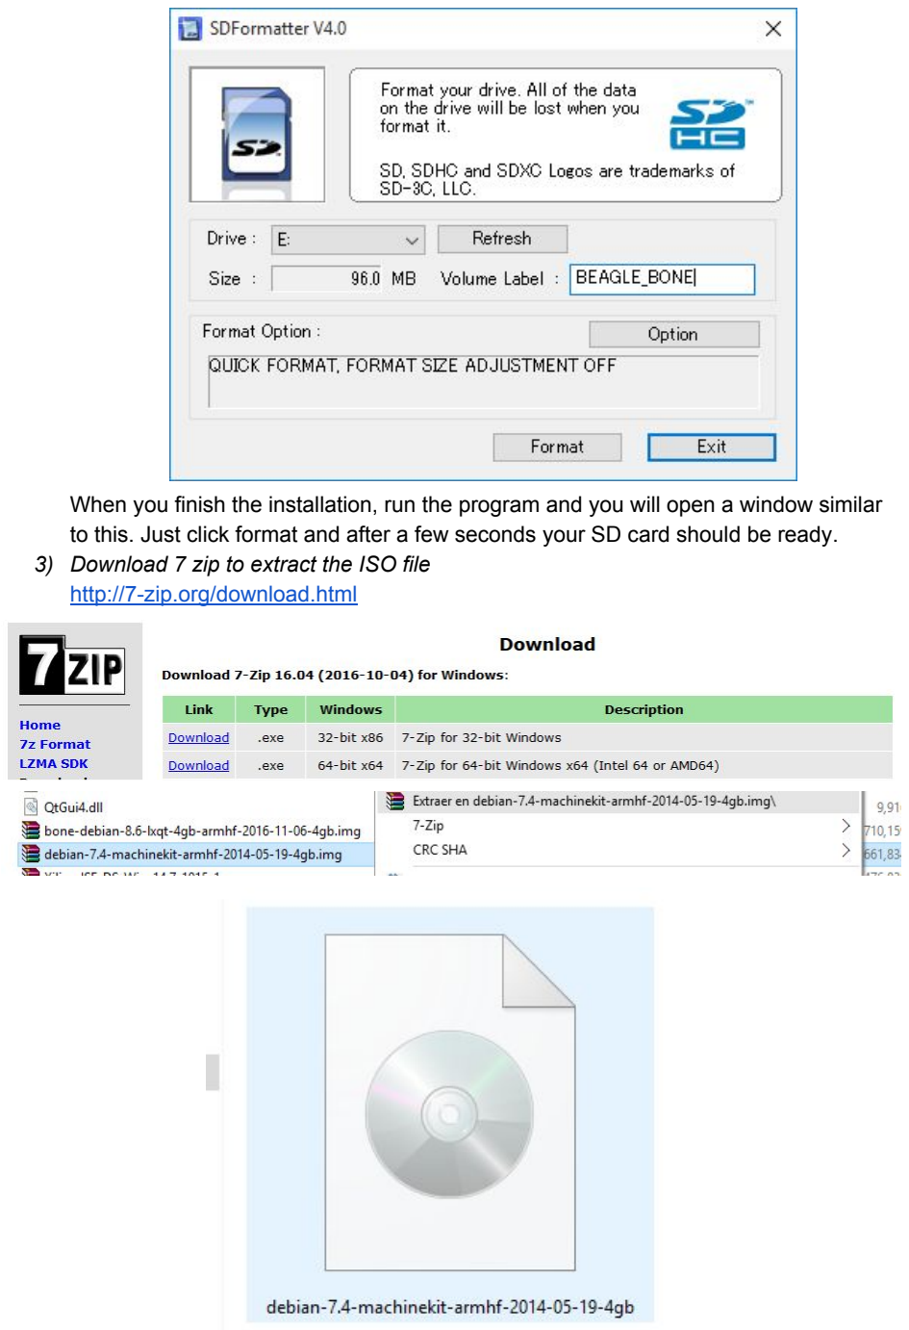
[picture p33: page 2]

When you finish the installation, run the program and you will open a window similar to this. Just click format and after a few seconds your SD card should be ready.
3) Download 7 zip to extract the ISO file
http://7-zip.org/download.html

4) Download Win32 Disk Imager to write the image into the SD card https://sourceforge.net/projects/win32diskimager/files/Archive/

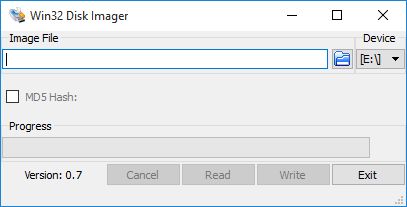
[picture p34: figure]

Select the SD card in the field for the Device and then click the blue folder to the left of the name of the device to search for your .img file. When you select it, the Write option will be enabled. Then the process will start.

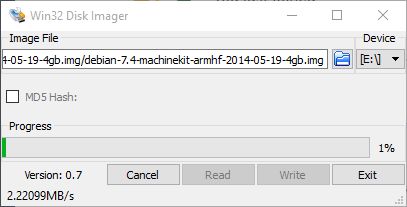
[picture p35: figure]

5) Install the drivers for the BBB

https://learn.adafruit.com/ssh-to-beaglebone-black-over-usb/installing-drivers-windows

6) Boot up the OS on the BBB
When the process of writing the image into the SD card is finished, plug it in into the Beaglebone Black and connect it via USB to your computer. For this step you will need to download Putty (http://www.putty.org/) in order to SSH the BBB. The default IP address for the BBB is 192.168.7.2, so you will need to type it when you open Putty. Open the Network and Sharing Center t o check out if the BBB is being detected as a Unidentified network.

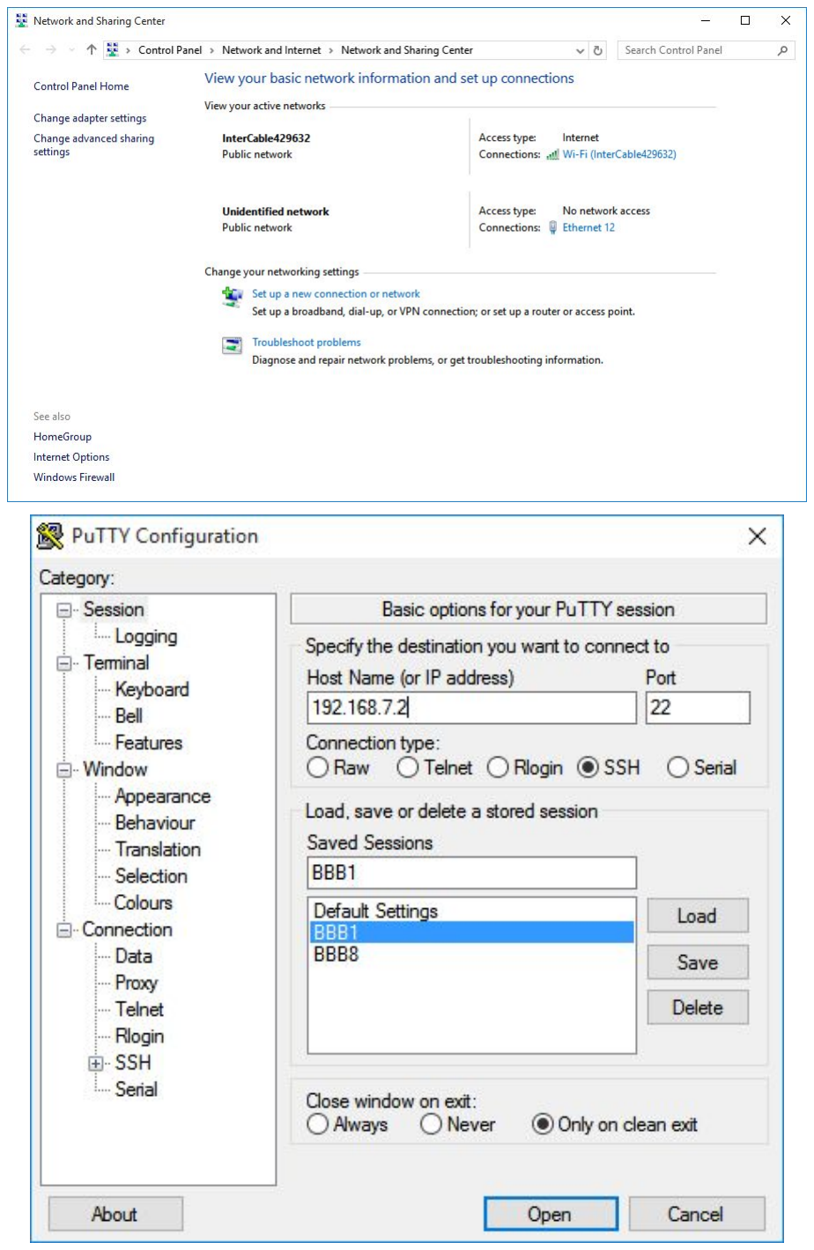
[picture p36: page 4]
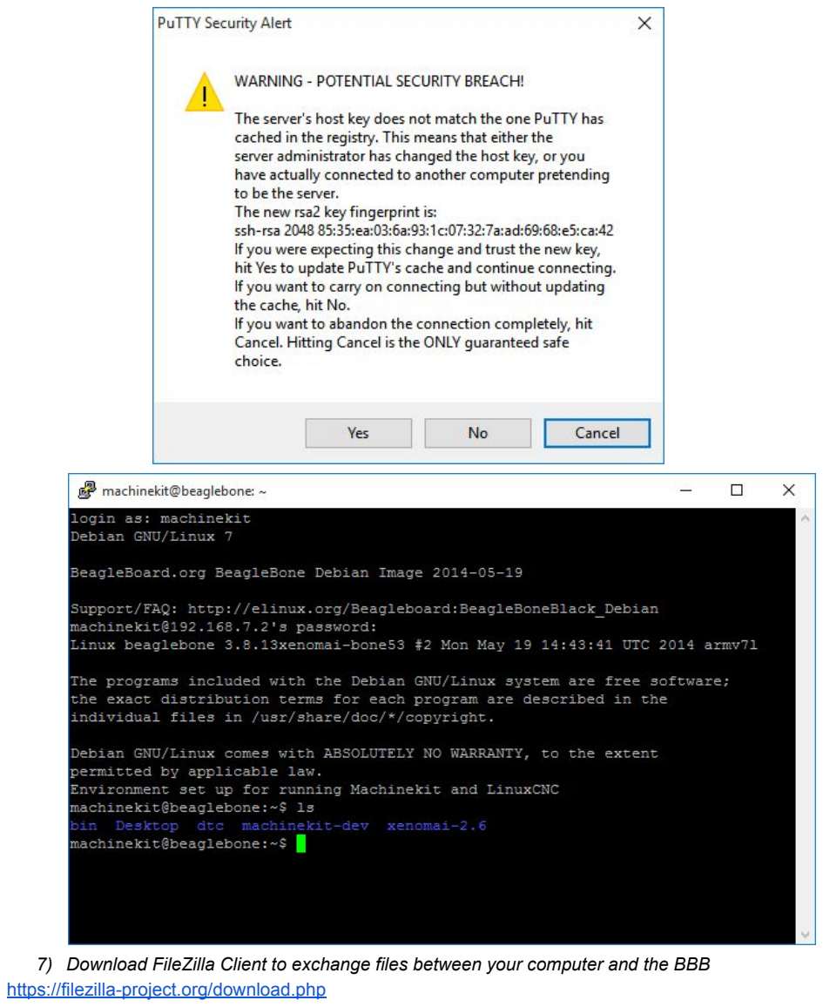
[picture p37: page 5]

7) Download FileZilla Client to exchange files between your computer and the BBB https://filezilla-project.org/download.php

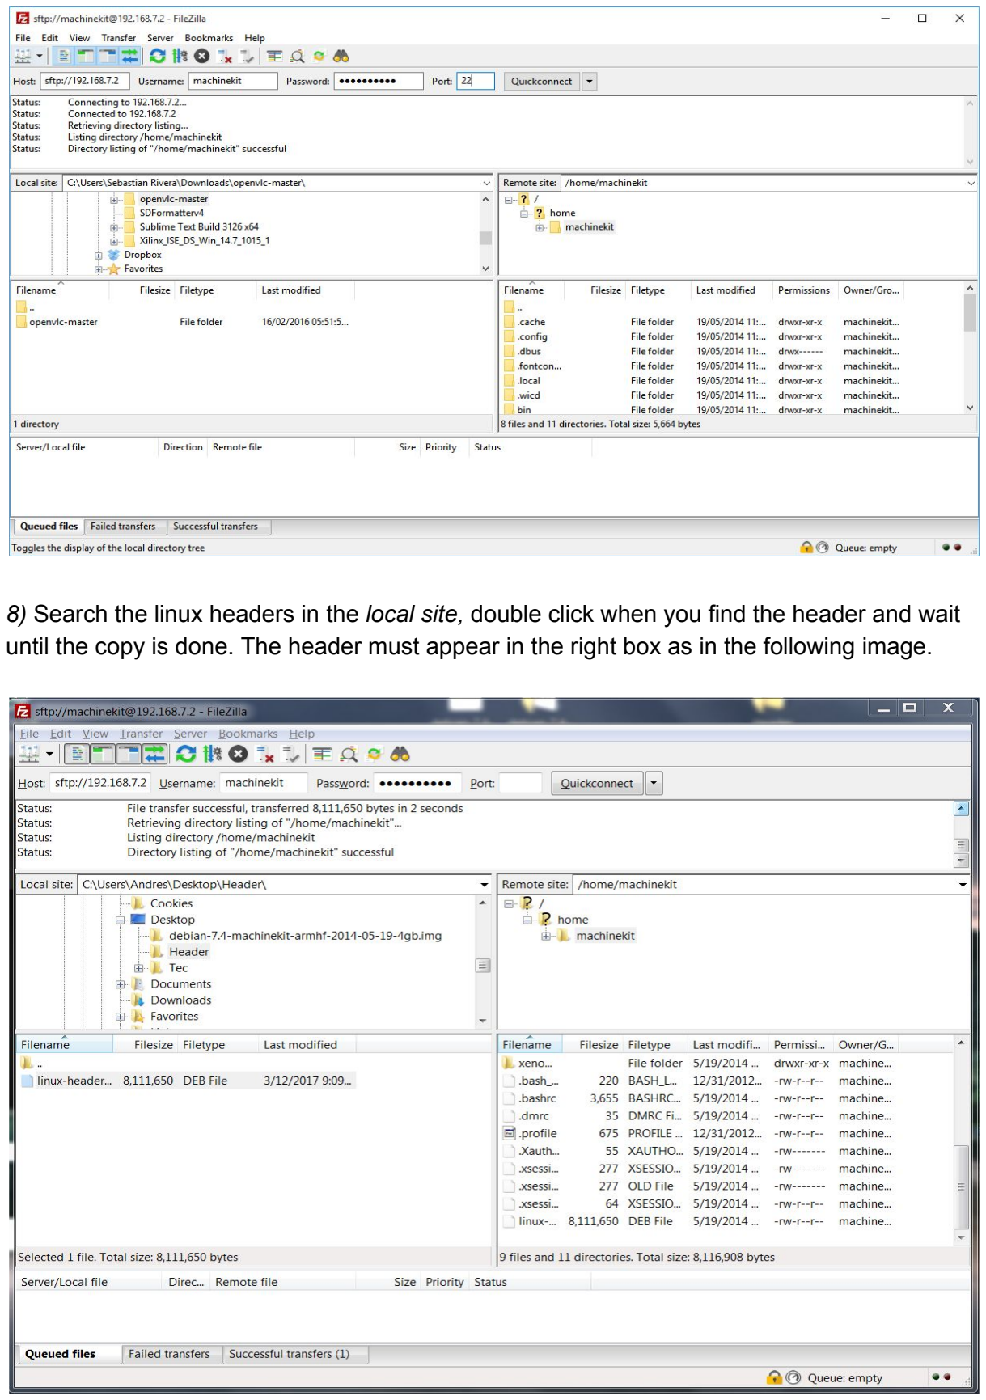
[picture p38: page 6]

8) Search the linux headers in the local site, double click when you find the header and wait until the copy is done. The header must appear in the right box as in the following image.

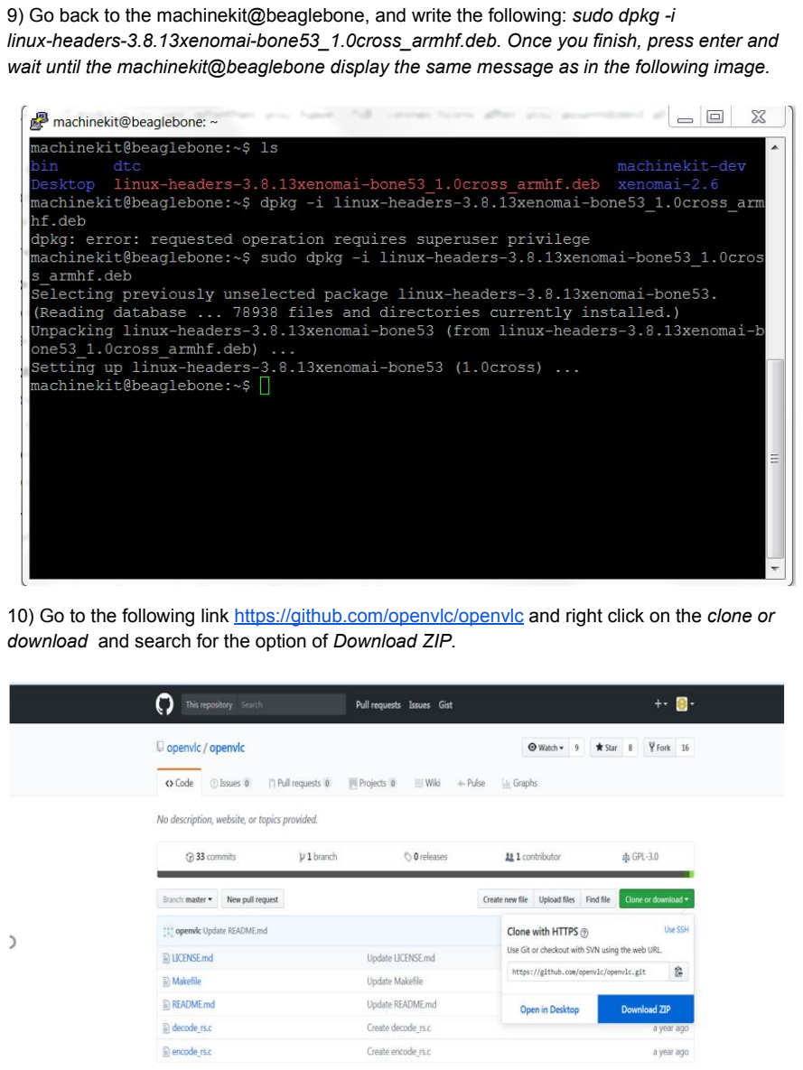
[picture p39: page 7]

9) Go back to the machinekit@beaglebone, and write the following: sudo dpkg -i linux-headers-3.8.13xenomai-bone53_1.0cross_armhf.deb. Once you finish, press enter and wait until the machinekit@beaglebone display the same message as in the following image.
10) Go to the following link https://github.com/openvlc/openvlc and right click on the clone or download and search for the option of Download ZIP.

11) Go back to Filezilla and find the openvlc-master and do the same steps as when you transfer the headers (8). After that go back to the machinekit@beaglebone and go to the openvlc-master file, once you are there write: make clean; make wait until machinekit@beaglebone displays the same message as the following image.

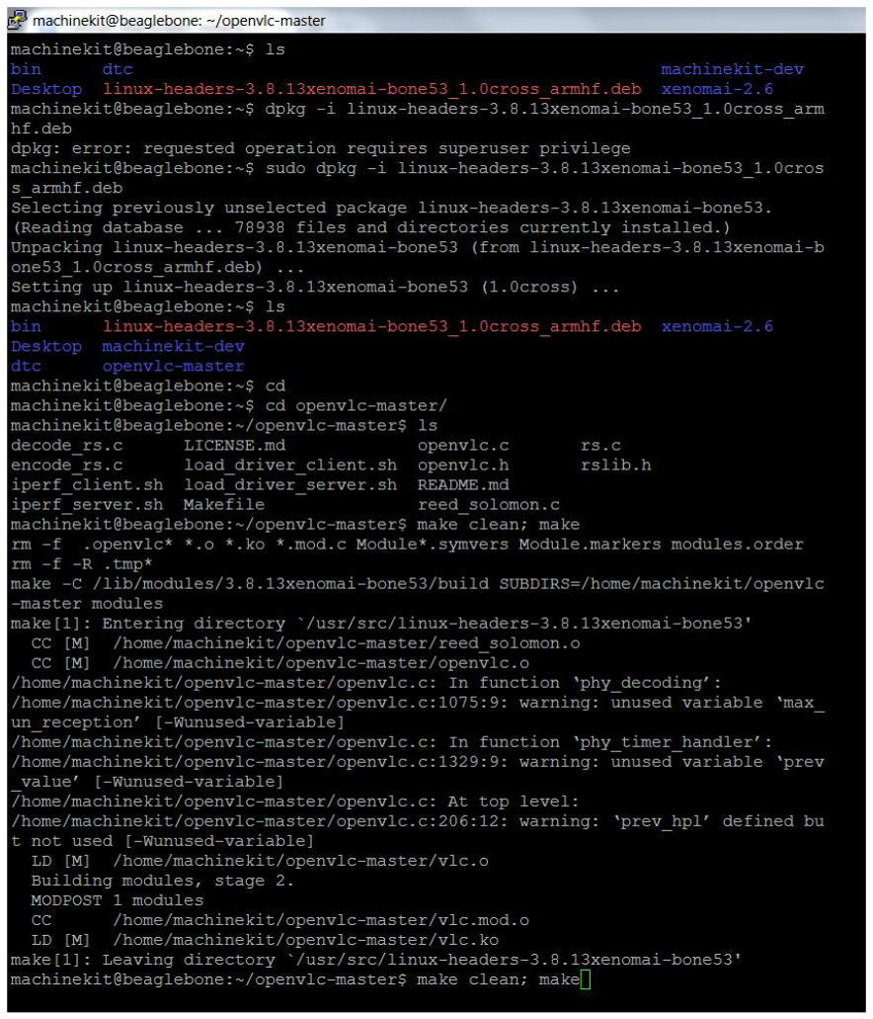
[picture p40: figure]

12) A vlc.ko file must be generated, now we have to focus on 2 files the load_driver_server.sh and the load_driver_client.sh. Write the instruction: nano load_driver_server.sh, a chart must appear like the following image.

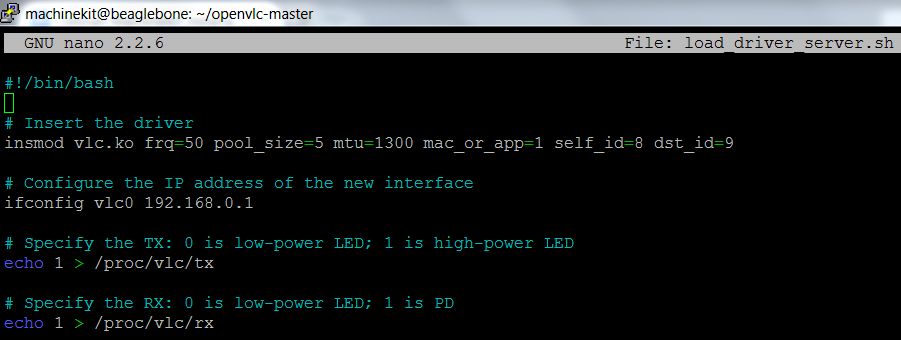
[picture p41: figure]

Notice that next to the word echo is the number 1, change both echo number 1 into 0. Then press control + x and y to save the changes. The result must look like the following image.

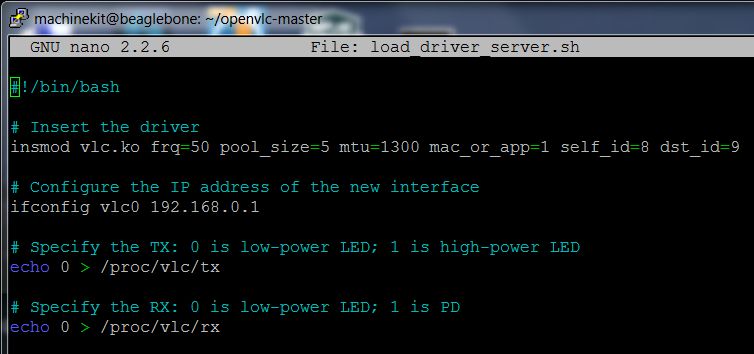
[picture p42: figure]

13) Do the same steps as in 12 for load_driver_client.sh. The machinekit@beaglebone must look like the following image.

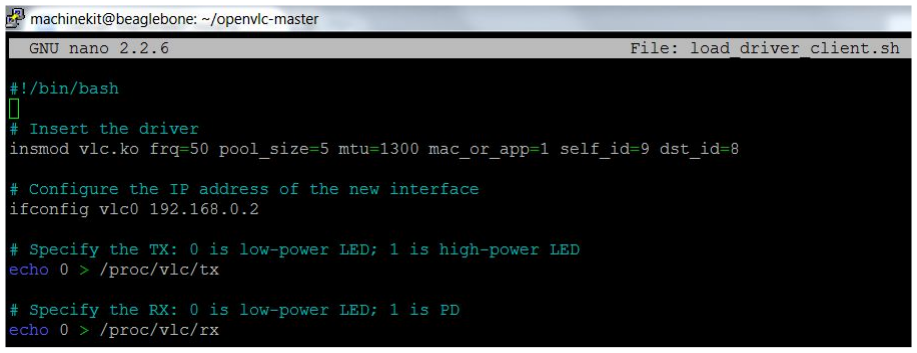
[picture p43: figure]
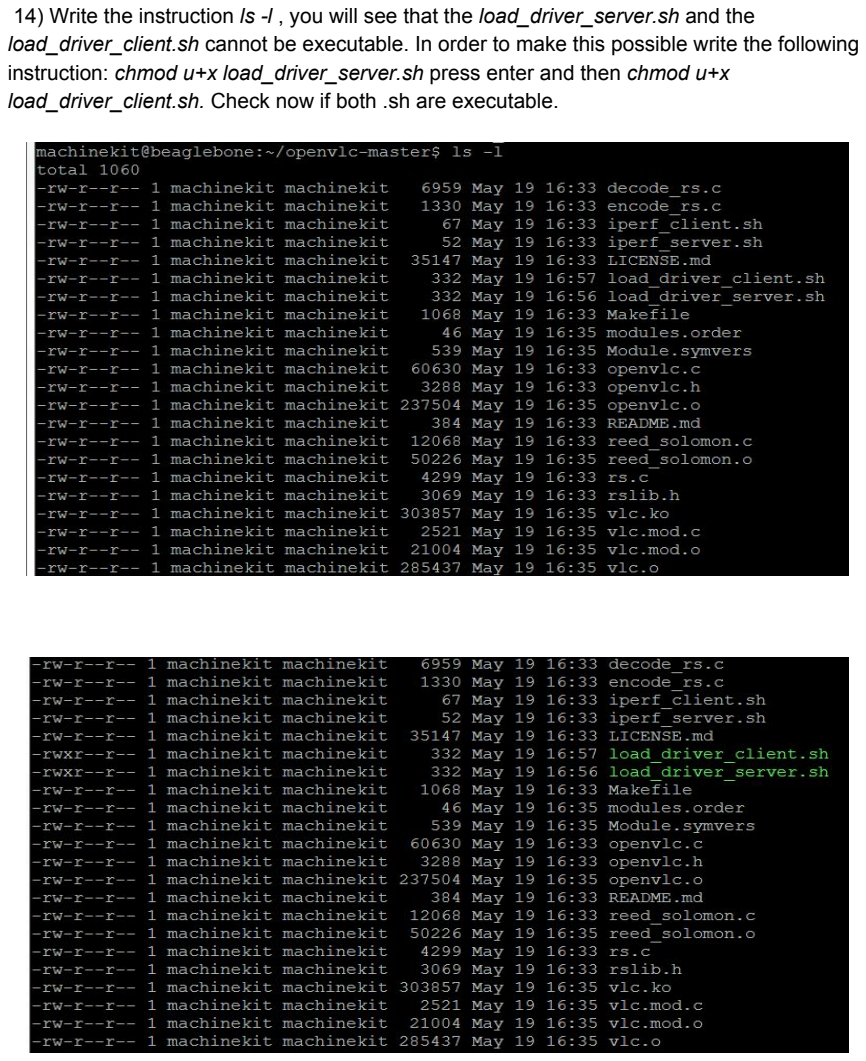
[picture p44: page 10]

14) Write the instruction ls -l , you will see that the load_driver_server.sh and the load_driver_client.sh cannot be executable. In order to make this possible write the following instruction: chmod u+x load_driver_server.sh press enter and then chmod u+x load_driver_client.sh. Check now if both .sh are executable.

14) Finally we have to verify if the installation was successful. We will develop a little test with 2 beagle bones, person A must write the instruction: sudo ./load_driver_client.sh and person B must write the instruction: sudo ./load_driver_server.sh. After that person A must write the instruction: ping 192.168.0.1 and person B must write the instruction ping 192.168.0.2. (Make sure that the led is already place in the BBB). As soon as the instruction is introduced to the machinekit@beaglebone the led will start to turn on and off, stay both beagle bones close and in the machinekit@beaglebone it will display this message. (To stop the program press control + c).

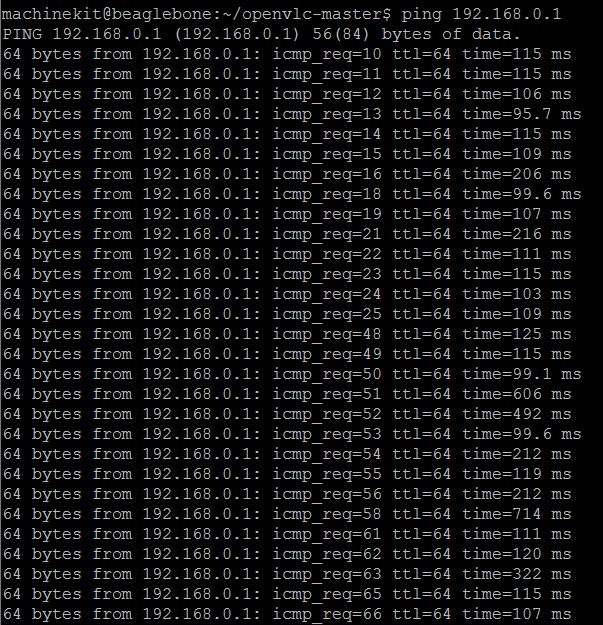
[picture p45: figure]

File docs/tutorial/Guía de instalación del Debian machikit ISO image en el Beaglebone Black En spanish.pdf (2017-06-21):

### Guía de instalación del Debian machikit ISO image en el Beaglebone Black - Windows

Esta guía tiene como propósito de explicar paso a paso como escribir un ISO image en la tarjeta SD para posteriormente usarla en el Beaglebone Black (BBB). El sistemas operativo usado para esta guía es Windows 10. La información oficial está ubicada en la página de internet del proyecto: http://www.openvlc.org/openvlc.html. Antes de empezar, asegúrese de tener una conexión de internet estable para poder descargar con normalidad los softwares para las siguientes instrucciones.

### Instalacion paso a paso

1. Descargue el Debian machinekit image. Para descargar el image siga el siguiente link: https://drive.google.com/file/d/0BwGT2J3dvAfNOEVibS1KQ2d5MGc/view. Cuando la descarga este completa modifique el nombre del archivo. Cambiarlo de .img.xz a .img.
2. Formatear la tarjeta SD.
https://www.sdcard.org/downloads/formatter_4/

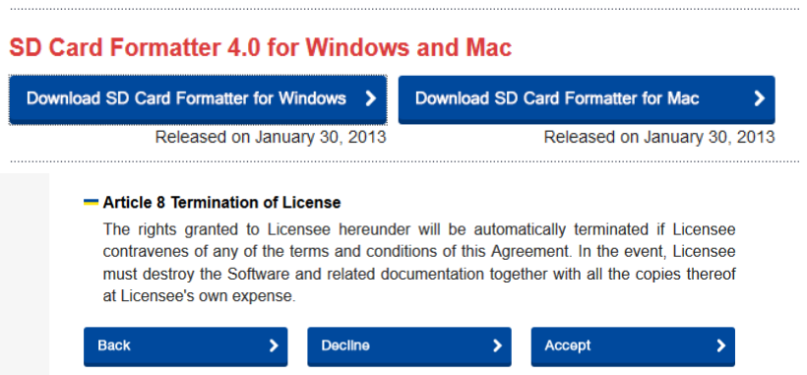
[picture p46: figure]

Cuando le dé clic para aceptar, debería comenzar a descargar. Extraiga los archivos del .zip folder y en este encontrara un archivo .exe. Córralo y la ventana de instalación aparecerá, a continuación, proceda a instalar la SD Formatter.

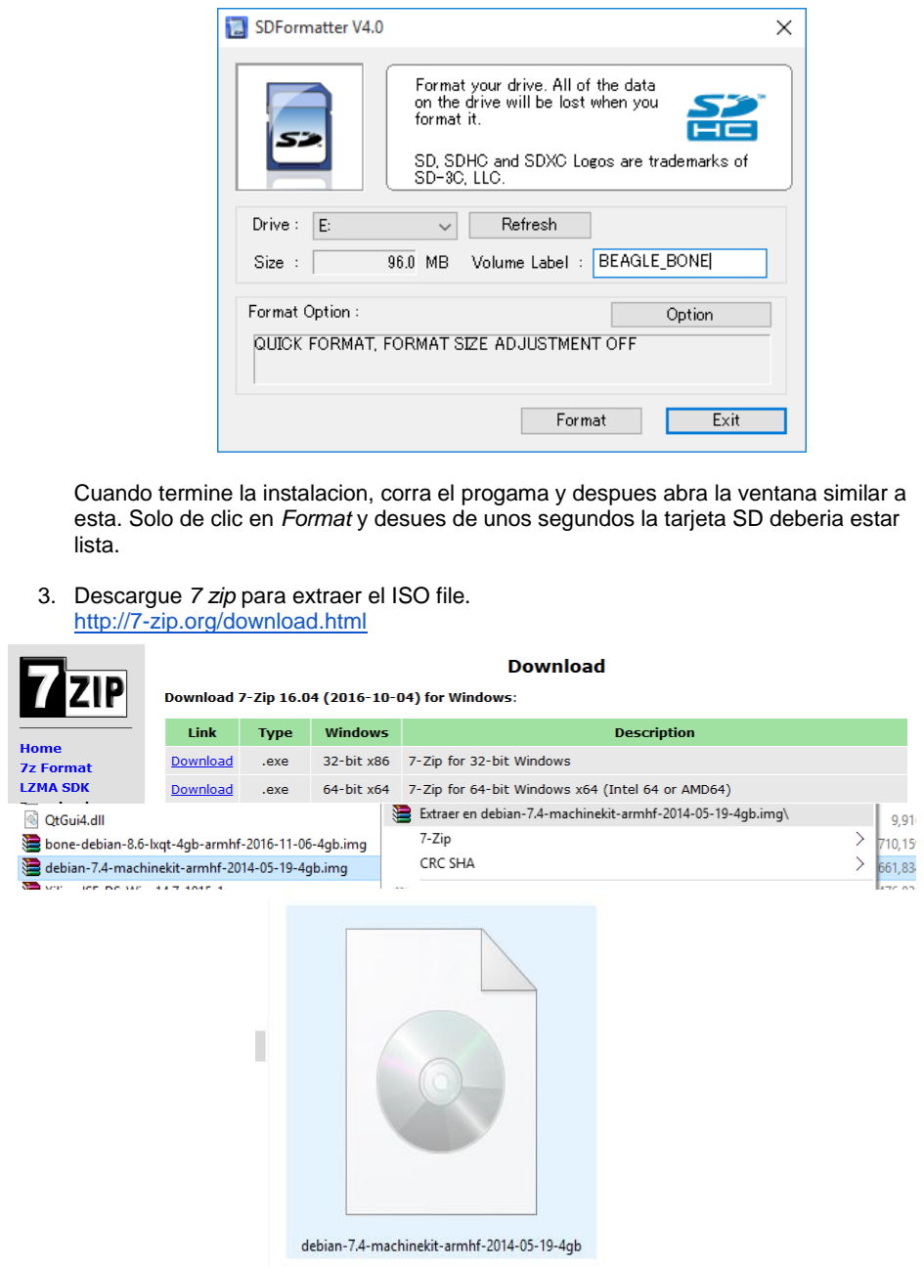
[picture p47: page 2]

Cuando termine la instalacion, corra el progama y despues abra la ventana similar a esta. Solo de clic en Format y desues de unos segundos la tarjeta SD deberia estar lista.

3. Descargue 7 zip para extraer el ISO file.
http://7-zip.org/download.html

4. Descargue Win32 Disk Imager para escribir el image a la tarjeta SD. https://sourceforge.net/projects/win32diskimager/files/Archive/

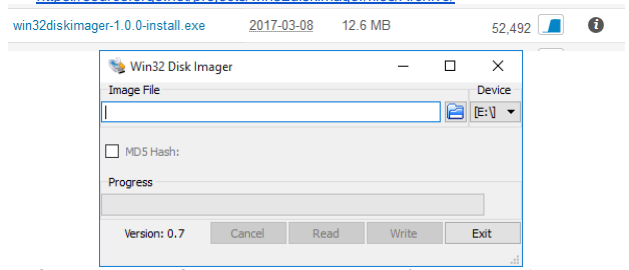
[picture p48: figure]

Seleccione la tarjeta SD en el lugar de Device y después haga clic en el folder azul y busque su archivo .img. Cuando lo seleccione, la opción de Write estaré disponible. Después el proceso comenzara.

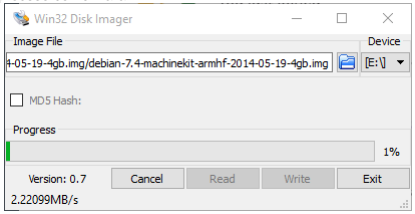
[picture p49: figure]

5. Instalar los drivers del BBB. https://learn.adafruit.com/ssh-to-beaglebone-black-over-usb/installing-drivers-windows
6. Arrancar el OS en el BBB
Cuando el proceso de escribir image en la tarjeta SD esté terminado, conéctelo al BeagleBone Black y también conecte este por USB a la computadora. Para este paso usted deberá descargar Putty (http://www.putty.org/) para poder SSH de BBB. La dirección de ip indeterminada para el BBB es 192.168.7.2, entonces usted tendrá que escribirlo al momento de ingresar al software Putty. Abrir el Network and Sharing Center para revisar si el BBB está siendo detectado como un Unidentified network.

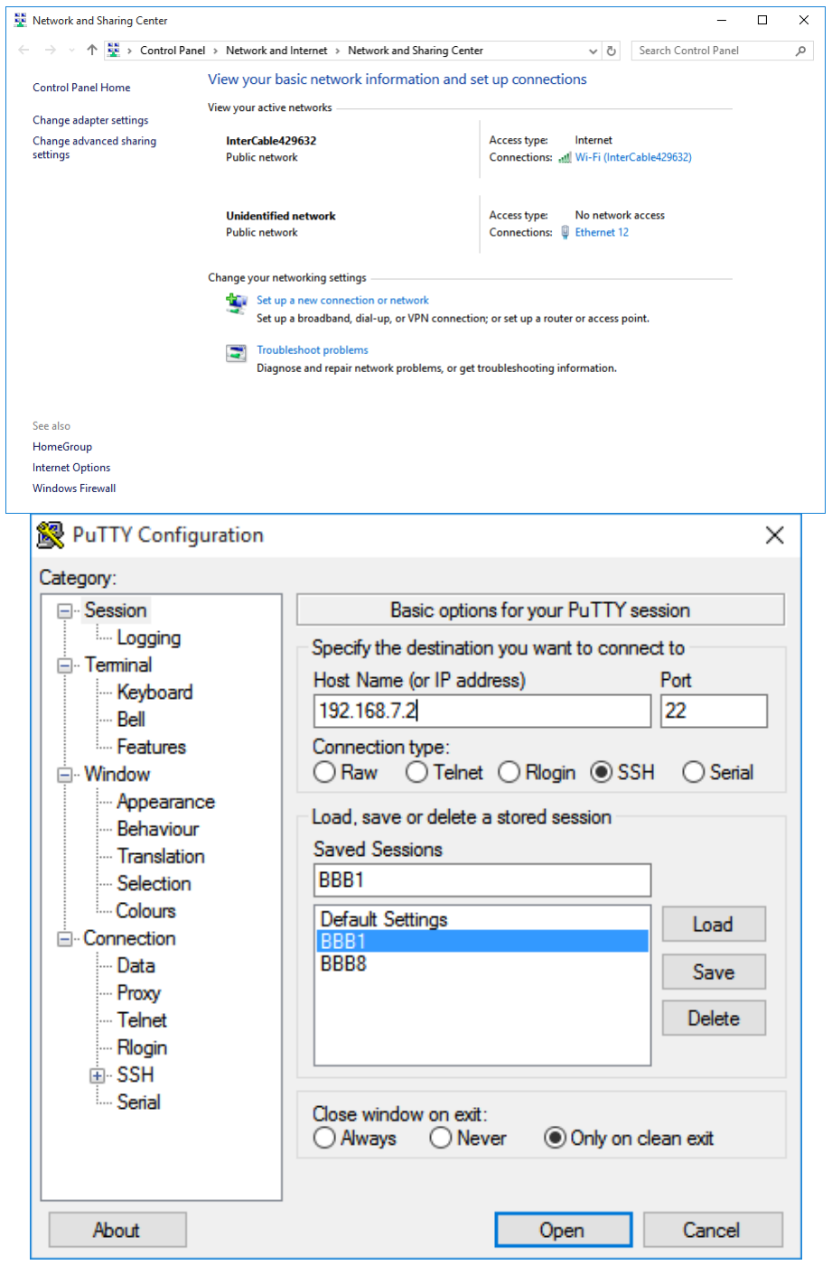
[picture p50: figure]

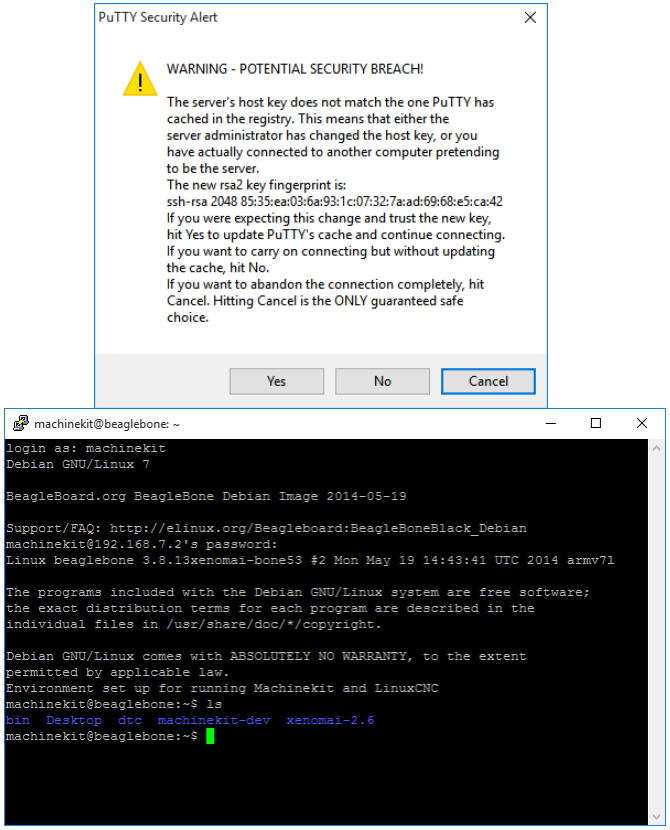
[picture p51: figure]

7. Descargar FileZillza Client para poder intercambiar archivos entre la computadora y el BBB.
https://filezilla-project.org/download.php

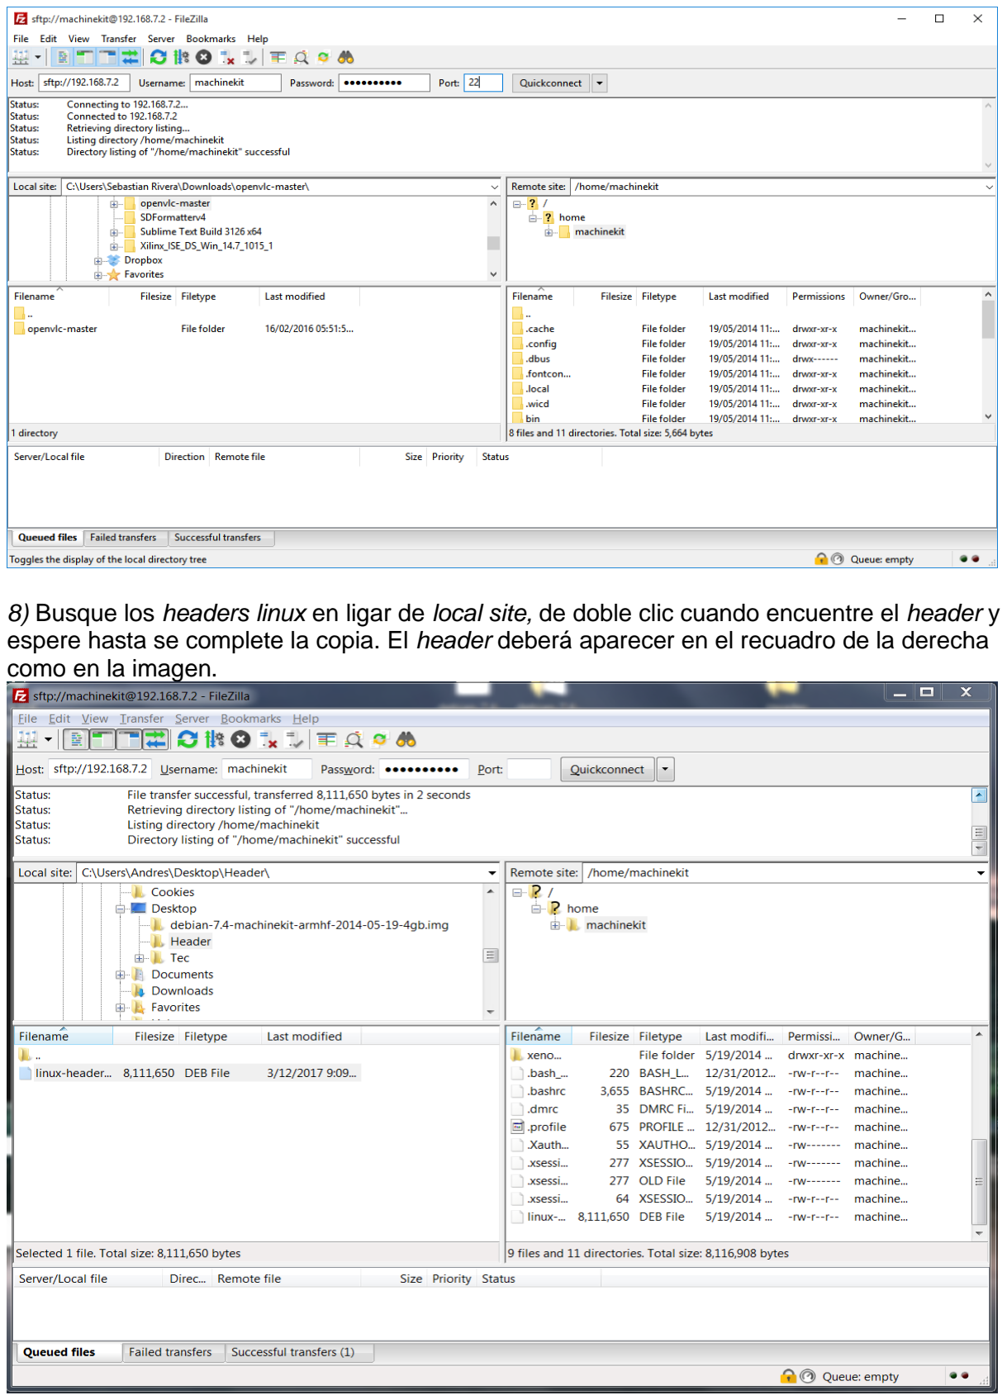
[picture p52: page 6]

8) Busque los headers linux en ligar de local site, de doble clic cuando encuentre el header y espere hasta se complete la copia. El header deberá aparecer en el recuadro de la derecha como en la imagen.

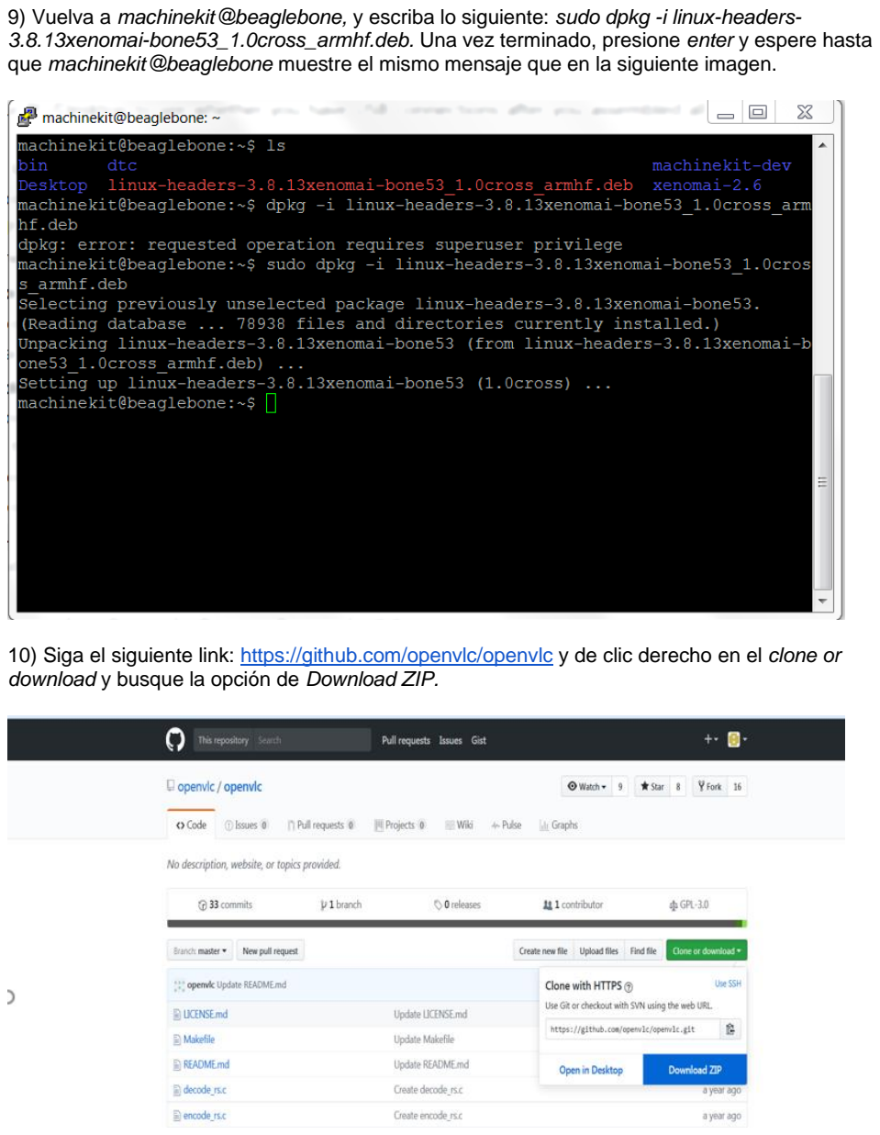
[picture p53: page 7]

9) Vuelva a machinekit@beaglebone, y escriba lo siguiente: sudo dpkg -i linux-headers-3.8.13xenomai-bone53_1.0cross_armhf.deb. Una vez terminado, presione enter y espere hasta que machinekit@beaglebone muestre el mismo mensaje que en la siguiente imagen.
10) Siga el siguiente link: https://github.com/openvlc/openvlc y de clic derecho en el clone or download y busque la opción de Download ZIP.

11) Vuelva a Filezilla y encuentre openvlc-master y siga los mismos pasos como cuando transferimos los headers (8). Despues regresar al machinekit@beaglebone y dirigirse a openvlc-master file, una vez que se encuentre en ese lugar escribir lo siguiente: make clean; make esperar hasta que se despliegue el mensaje de la imagen de abajo.

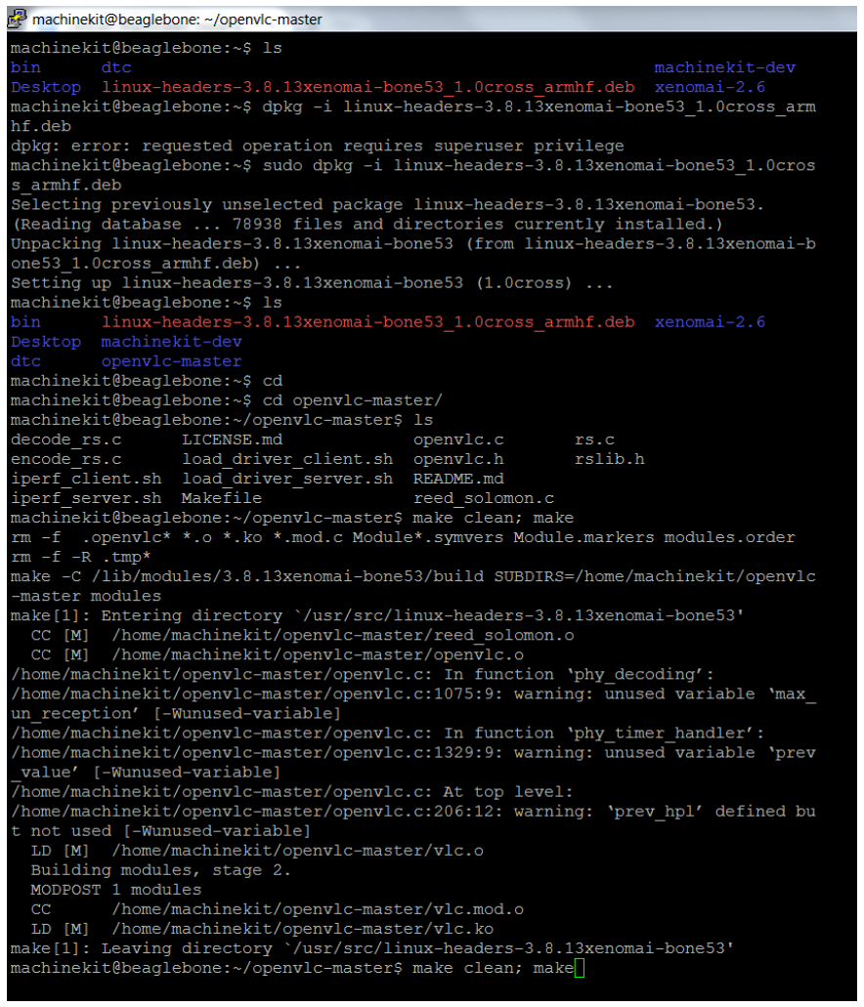
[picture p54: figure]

12) Un archive vlc.ko sera genrado, ahora tenemos que enfocarnos en 2 archivos el load_driver_server.sh and the load_driver_client.sh. Escribir la instrucción: nano load_driver_server.sh un cuadro deberá aparecer como en la fotografía.

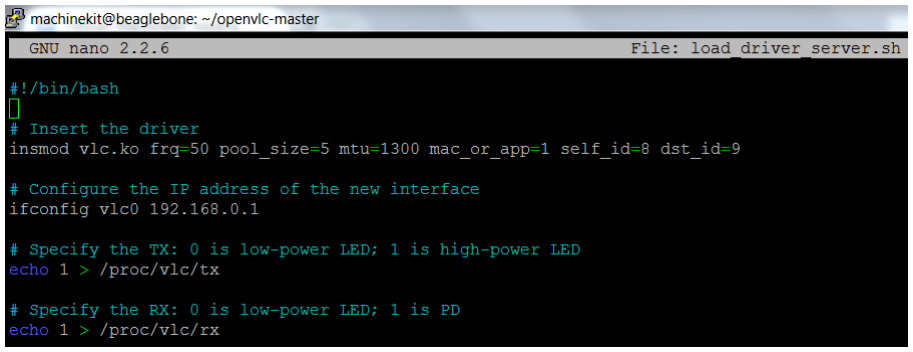
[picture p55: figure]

Identifique la palabra echo, al lado de esta tiene el valor de 1, cambiarlo por el valor de 0. A continuación presionara las teclas “control” + “x” y “y” para guardar los cambios.

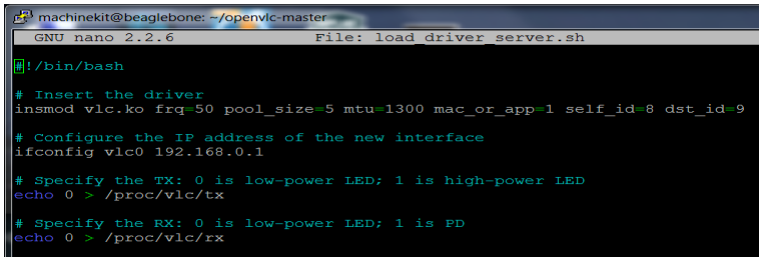
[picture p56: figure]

13) Hacer los mismos pasos que en 12 para el load_driver_client.sh. El machinekit@beaglebone deberia verse como la siguiente imagen.

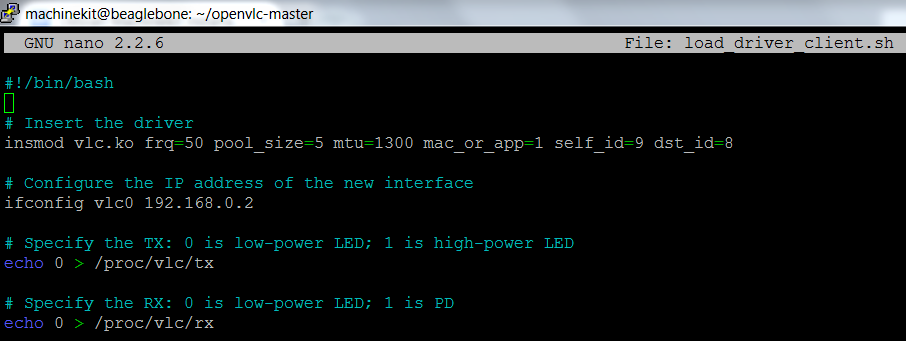
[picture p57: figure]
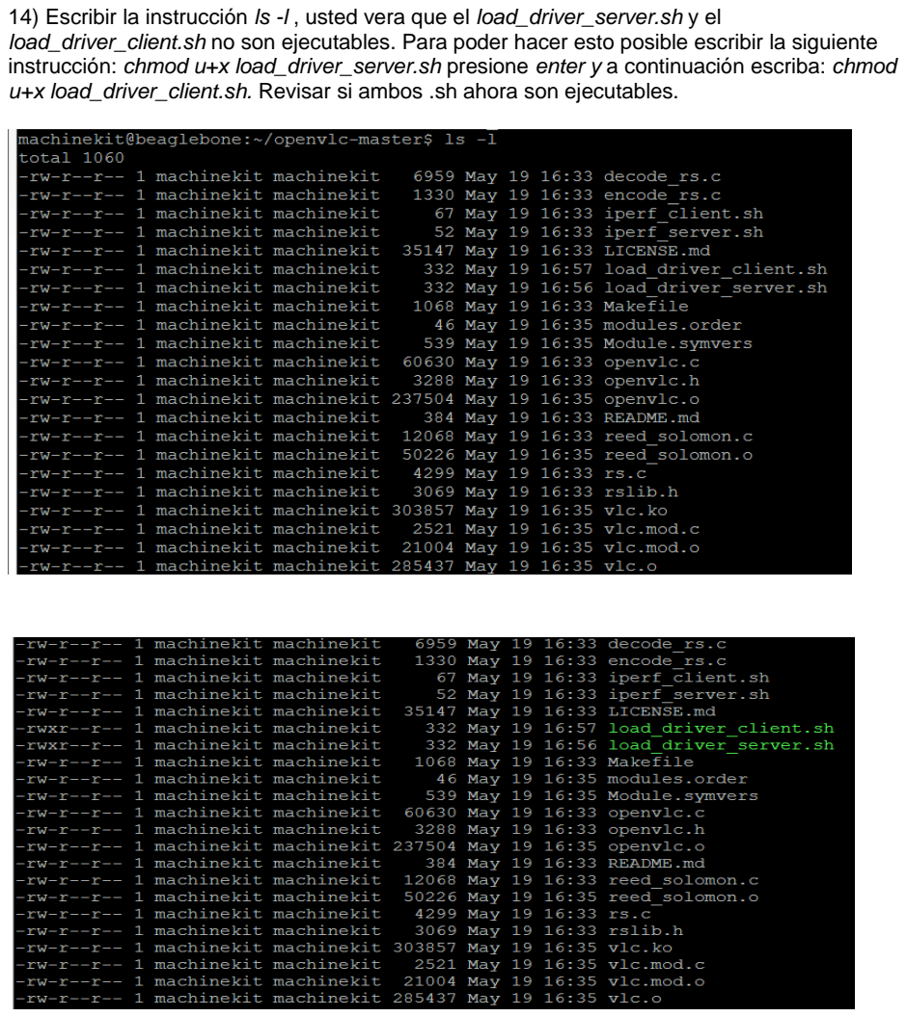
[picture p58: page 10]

14) Escribir la instrucción ls -l , usted vera que el load_driver_server.sh y el load_driver_client.sh no son ejecutables. Para poder hacer esto posible escribir la siguiente instrucción: chmod u+x load_driver_server.sh presione enter y a continuación escriba: chmod u+x load_driver_client.sh. Revisar si ambos .sh ahora son ejecutables.

15) Finalmente para verificar la correcta instalación se realizará una pequeña prueba con 2 BBB, La persona A deberá escribir la siguiente instrucción: sudo ./load_driver_client.sh y la persona B: sudo ./load_driver_server.sh. Después de eso la persona A deberá escribir la instrucción: ping 192.168.0.1 y la persona B deberá escribir la instrucción: ping 192.168.0.2 (Asegúrese de que los leds de cada BBB estén conectados). Apenas se introduzca la instrucción al machinekit@beaglebone el led comenzara a encender y apagarse. Colocar ambos BBB de frente y observar los valores que se despliegan en el machinekit@beaglebone. (Para detener el programa presione control + c).

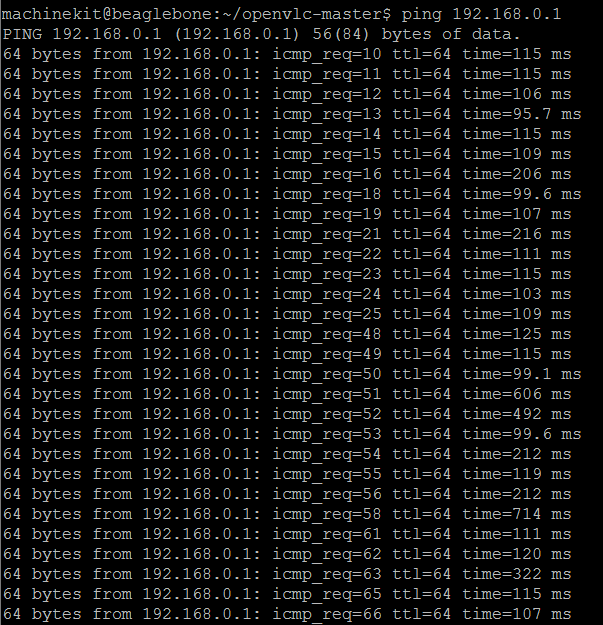
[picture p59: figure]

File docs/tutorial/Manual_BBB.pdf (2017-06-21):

OPEN VLC
Instalación del sistema operativo Debian(machinekit) en la memoria SD.

Este documento sigue las instrucciones para realizar la instalación experimental para OPENVLC. Un proceso similar se encuentra en la página de openvlc.org: http://www.openvlc.org/openvlc.html
Pasos
1. Descargar la imagen de DEBIAN del siguiente link:
- https://drive.google.com/file/d/0BwGT2J3dvAfNOEVibS1KQ2d5MGc/view
- Remover la extensión .xz y quedarse con la .ISO
- Guardarlo ya que la usaremos en los próximos pasos
2. Formatear la memoria SD. SDFormatter puede ser utilizado para esto.
- Puede ser descargado en: https://www.sdcard.org/downloads/formatter_4/eula_mac/
- La interface gráfica debe verse como la siguiente:


- Seleccionar la memoria y dar click en formatear. Debe tomar algunos segundos.
3. Ahora es momento de quemar la imagen en la memoria SD. Por simplicidad, descargue Etcher: https://etcher.io/ . Seleccione el archivo ISO de Debian y la memoria SD.


- Dependiendo del tamaño de la memoria SD, el proceso podría tardar alrededor de 20 minutos.
- Remueva y vuelva a insertar la memoria SD. Ahora se debería de poder observar “BEAGLE_BONE” como el nombre del dispositivo.


4. Inserte la memoria SD en la Beagle Bone y conecte el dispositivo a través del puerto USB. Espere un momento en lo que la computadora reconoce a la Beagle Bone. En este momento, la dirección IP para la Beagle Bone debería de ser 192.168.7.2. Ahora antes de continuar, es necesario instalar dos drivers.
- Para confirmar que la Beagle Bone ha sido reconocida, abra un navegador y escriba la dirección IP antes mencionada. Usted debería de ver algo así:


- De no poder observar la imagen anterior, usted ha hecho algún paso de la manera incorrecta.
- Los drivers para MAC se encuentran en la sección get started en la página beagleboard.org.
- https://beagleboard.org/getting-started#step2
- DESCARGUE E INSTALE AMBOS: El serial driver y network driver. Después de instalar los drivers, reinicie la computadora. IMPORTANTE: MIENTRAS REINICIA LA COMPUTADORA, NO DESCONECTE LA BEAGLE BONE BOARD.
5. Después de reiniciar la computadora, vaya a System Preferences -> Networks. Debería de observar que la Beagle Bone ya es reconocida.


6. Ahora es momento de utilizar SSH. Abra la terminal y ejecute el siguiente comando:
- ssh machinekit@a92.168.7.2, enter y responda yes a la pregunta


- Se le pedirá un password. El password es el mismo que el usuario: machinekit
- Una vez que haya hecho esto, usted ya se encontrara dentro de la Beagle Bone. Ejecute el comando –ls para observar los folders.


7. Ahora necesitamos instalar los headers de Linux. Descárguelos del siguiente link:
- https://drive.google.com/file/d/0BwGT2J3dvAfNcVljMTFUU2phQmc/view
- Necesitamos transferir los archivos a la Beagle Bone. Hay muchas maneras de transferir los archivos, esta vez lo haremos utilizando FileZilla. Descárguelo e instálelo. Una vez instalado, abra el programa y conéctese a la Beagle Bone por el puerto 22.
- Busque los headers de Linux, selecciónelos y arrástrelos al folder que se encuentra del otro lado de machine kit.


- Usted puede observar el archivo desde la terminal


- Ejecute el siguiente comando:
- sudo dpkg –i Linux-headers-3.8.13xenomai-bone53_1.0cross_armhf.deb
8. Ahora descargue la más reciente versión de openvlc de la página de github:
- https://github.com/openvlc/openvlc
- La Beagle Bone no tendrá acceso a internet. Descargue y descomprima el archivo y utilizando FileZilla, transfiera el folder como en el paso anterior.


9. Muévase al folder de openvlc, ejecutando el comando cd openvlc-master. Usted debería de ver los siguientes archivos. Ahora ejecute el comando make.
10. Hemos terminado la instalación.
- Antes de continuar, necesitamos modificar los archivos load_driver para poder hacer uso del LED.
- Para ambos archivos (load_driver_client y load_driver_server) es necesario cambiar las líneas de echo de la siguiente manera:
- echo > 1 a echo > 0
- Las líneas deben quedar como se muestra en la siguiente imagen:


- Una vez que ya haya terminado de modificar los archivos, guarde los cambios y ejecute el script. Utilice el comando ifconfig para confirmar que la instalación se ha realizado adecuadamente. Debe verse como en la siguiente imagen:

- Una vez que ambos archivos hayan sido modificados y el driver ha sido cargado, ejecute el comando ping.
- Ping 192.168.0.1
- El Led comenzará a encenderse y apagarse.
- Nota: Si usted trata de realizar ping a algún objetivo que se encuentra fuera de su LAN, va a desplegarse el siguiente mensaje:
- Connect: Network is unreachable

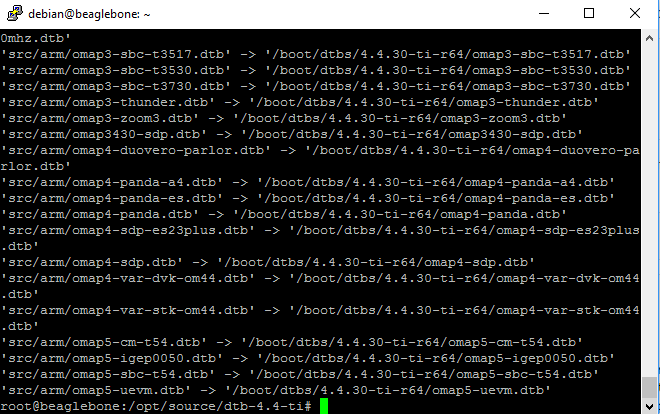
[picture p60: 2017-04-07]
docs/assignment/images/makeinstall.png

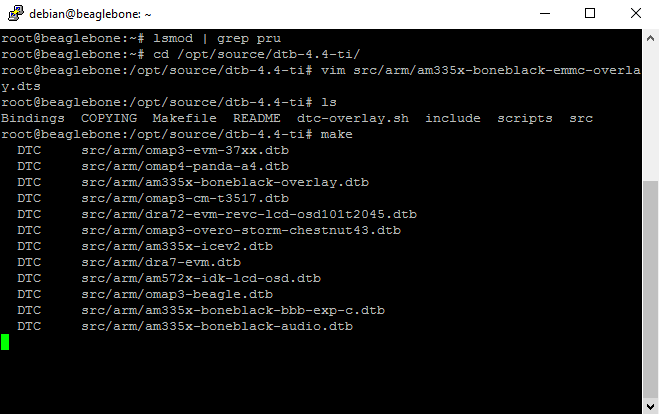
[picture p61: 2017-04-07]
docs/assignment/images/make.png

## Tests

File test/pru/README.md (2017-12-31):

### How to test the source file running in PRU ###
## Problem ##
Software development in PRU is limited by the debugging tools available in a single processor development. We can't use print or view all memory register in an conmercial IDE or use any JTAG related debugging tools. 
## Solution ##
Here we proposed two solutions to tackle this problem. The first solution is to test the code in userspace first as both PRU code and user space code are C99 compatible. 

 1. Make sure rx.c will general raw samples from the ADC. Meanwhile, the tx.c needs to send msgs continuously.
 2. Let's assume the msg.log contains the raw samples from the ADC. Before you apply the preprocess script. You'll need to hexdump it
```
hexdump -d msg.log >> msg.log
```
 3. Now you run the script to convert the msg.log file to a sequency of 0's and 1's for the source file to decode. This is when you'll have the test.txt file used by the test.c file.
 4. Compile test.c 
```
gcc test.c -o test
```
 5. Run the executable test.
```
test
```
 6. Now you will see the the decoded message in the terminal. You can insertprintf in all places you want for debugging purpose. 
 7. Enjoy!!!  

The second solution is to use one PRU as software development processor and the other PRU as the debugging processor. The purple board provideds an onboard RGB LED. As the two PRUs have shared memory. We can allocate a global pointer for these two PRU, and modify the value for this pointer in one PRU and check whether the value has been updated in the debugging PRU. If the value is updated, we can then blink the LED as the notice to the user such that the user knows exactly which code block has trigger the LED. 

PRU0
```
uint32_t *clockPointer = (uint32_t *)0x00010000;

while( *clockPointer == SOME INTEGER)
{
 	blink the led;
}
```

PRU1
```
uint32_t *clockPointer = (uint32_t *)0x00010000;

void blink(void)
{
	*clockPointer = SOME INTEGER;
}

```

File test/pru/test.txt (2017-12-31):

1
1
1
1
1
1
0
0
0
0
1
1
1
1
0
0
0
0
1
1
1
1
0
0
0
0
0
0
0
0
1
1
1
1
1
1
1
1
0
0
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

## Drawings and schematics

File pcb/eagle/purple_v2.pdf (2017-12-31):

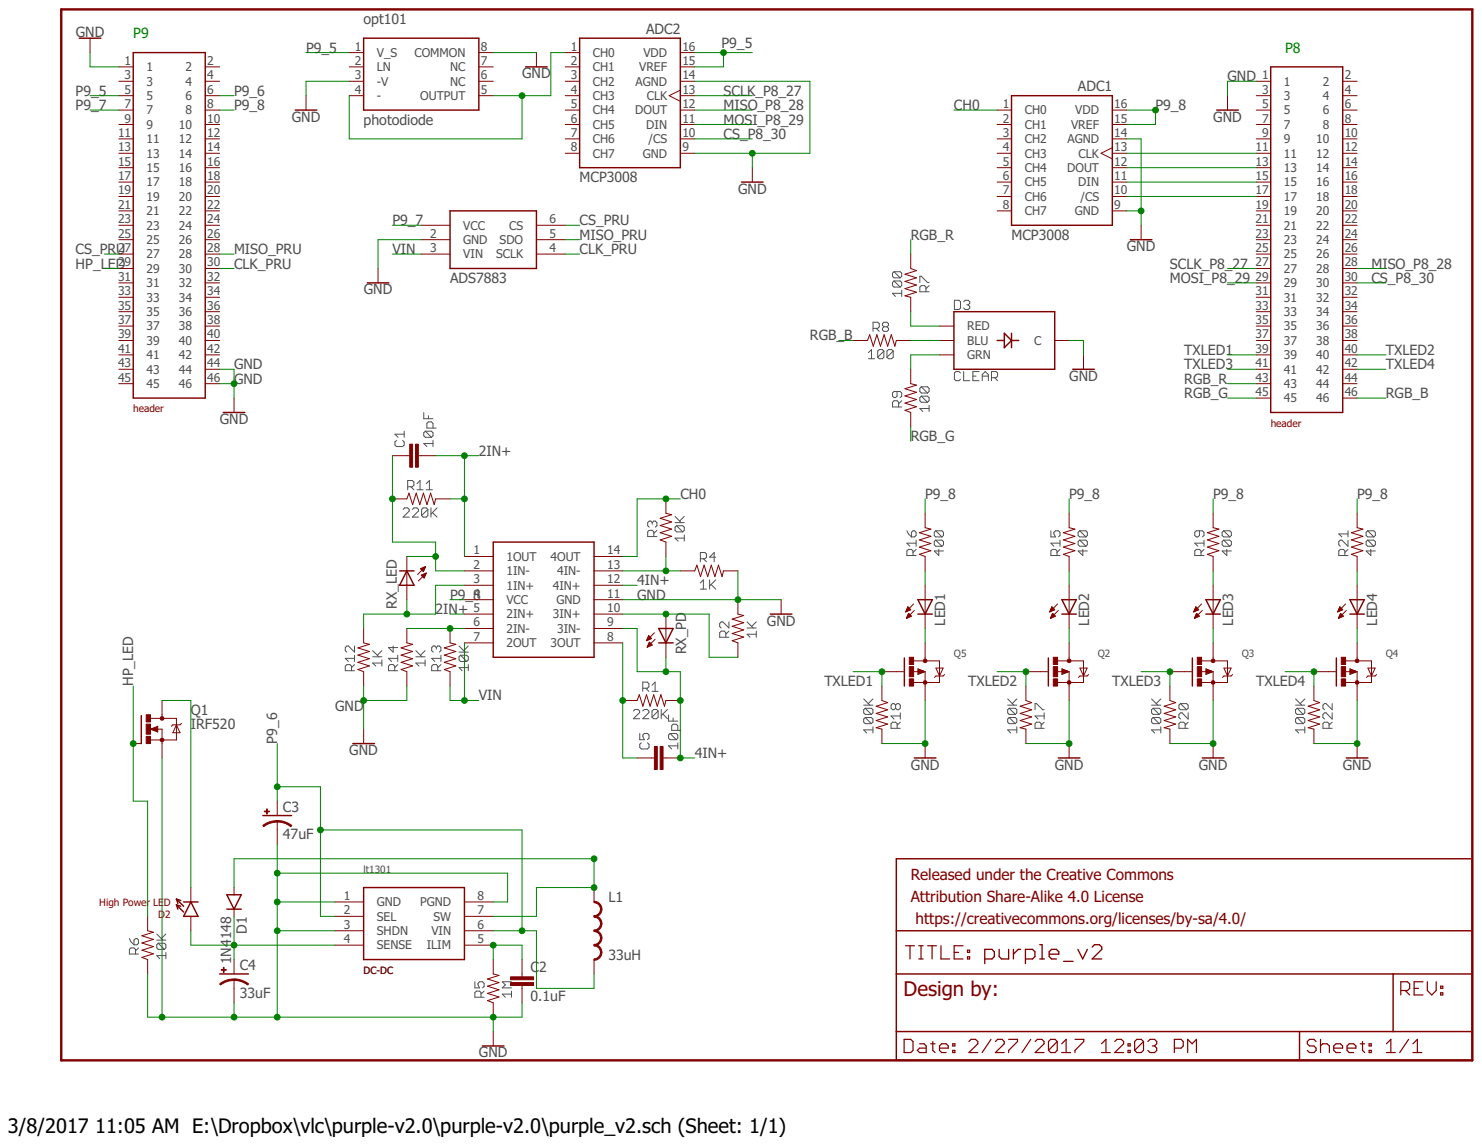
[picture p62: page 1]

Released under the Creative Commons Attribution Share-Alike 4.0 License https://creativecommons.org/licenses/by-sa/4.0/

3/8/2017 11:05 AM E:\Dropbox\vlc\purple-v2.0\purple-v2.0\purple_v2.sch (Sheet: 1/1)

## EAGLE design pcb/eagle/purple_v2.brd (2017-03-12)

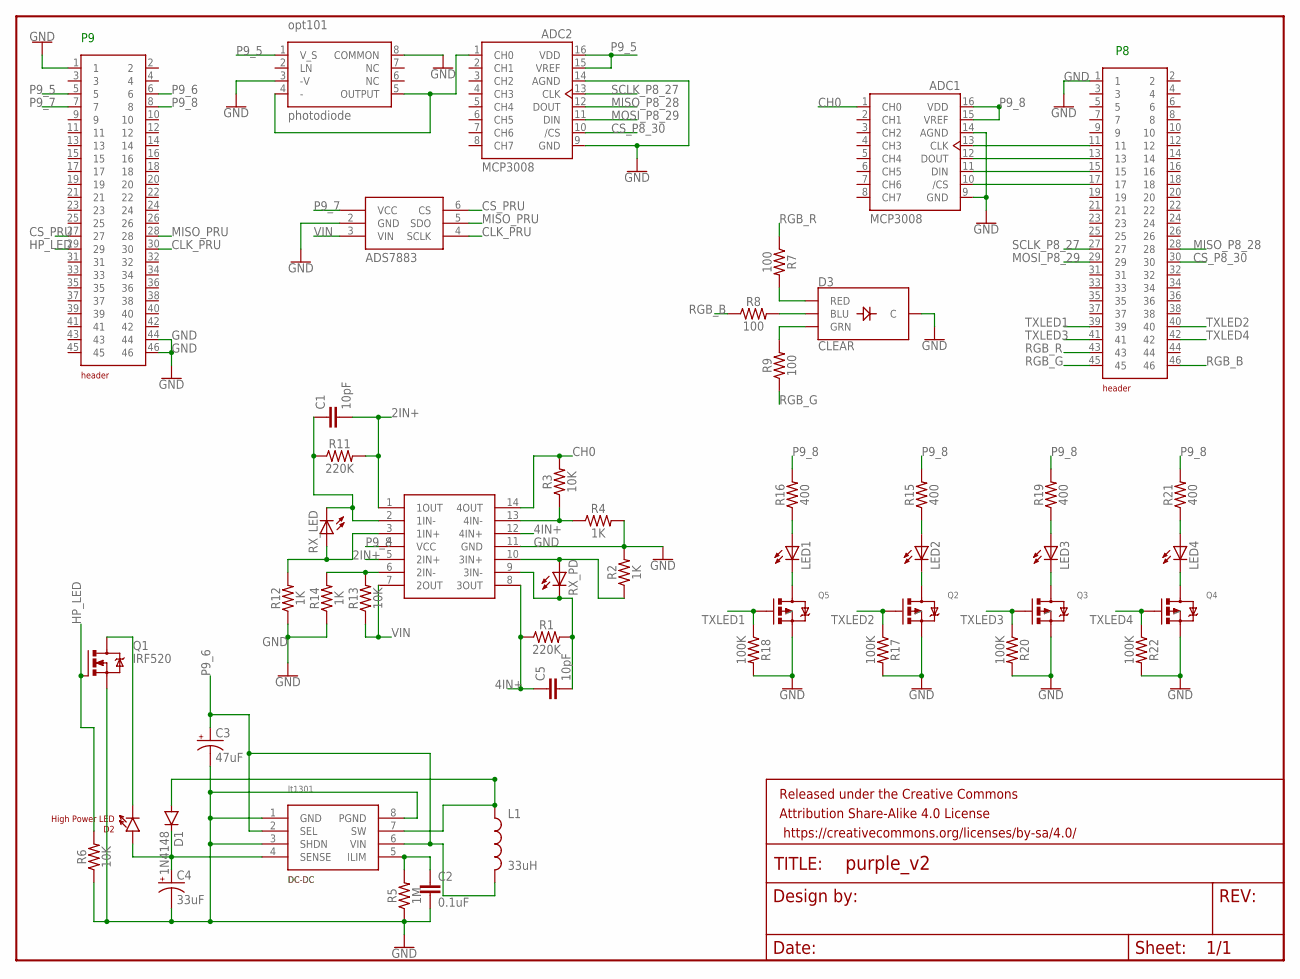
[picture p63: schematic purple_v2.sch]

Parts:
ADC1, ADC2: MCP3008-SO16; SO16
C1, C5: 10pF; 0603
C2: 0.1uF; CAP-PTH-SMALL
C3: 47uF; CPOL-RADIAL-10UF-25V
C4: 33uF; CPOL-RADIAL-10UF-25V
D1: 1N4148; DIODE-1N4148
D2: High Power LED; LTE-302
D3: CLEAR; LED-RGB-THRU
FRAME1: FRAME-LETTERNO_PACKAGE; DUMMY
J1, J2: 223; 2*23
L1: 33uH; RLB0912
LED1, LED2, LED3, LED4: LED5MM
OP-AMP: TLC2274-SO14; SO14
Q1: IRF520; TO220BV
Q2, Q3, Q4, Q5: MOSFET-PCHANNEL; SOT23-3
R1, R11: 220K; 0805
R2, R4, R12, R14: 1K; 0805
R3, R6, R13: 10K; 0805
R5: 1M; 0805
R7, R8, R9: 100; 0805
R15, R16, R19, R21: 400; 0805
R17, R18, R20, R22: 100K; 0805
RX_LED: LED5MM
RX_PD: LED5MM
U5: LT1301; DIL08
U9: OPT101
U$1: ADS7883; SOT23-6

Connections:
2IN+: C1.2, OP-AMP.1 (1OUT), OP-AMP.5 (2IN+), R11.2
4IN+: C5.1, OP-AMP.8 (3OUT), OP-AMP.12 (4IN+), R1.1
CH0: ADC1.1 (CH0), OP-AMP.14 (4OUT), R3.2
CLK_1: ADC1.13 (CLK), J2.11
CLK_PRU: J1.30, U$1.4 (SCLK)
CS_1: ADC1.10 (/CS), J2.17
CS_P8_30: ADC2.10 (/CS), J2.30
CS_PRU: J1.27, U$1.6 (CS)
DIN_1: ADC1.11 (DIN), J2.15
DOUT_1: ADC1.12 (DOUT), J2.13
GND: ADC1.9 (GND), ADC1.14 (AGND), ADC2.9 (GND), ADC2.14 (AGND), C2.2, C3.2 (-), C4.2 (-), D3.2 (C), J1.1, J1.44, J1.46, J2.1, OP-AMP.11 (GND), Q1.S, Q2.2 (S), Q3.2 (S), Q4.2 (S), Q5.2 (S), R2.2, R4.2, R5.1, R6.1, R12.1, R14.1, R17.2, R18.2, R20.2, R22.2, U5.1 (GND), U5.3 (SHDN), U5.8 (PGND), U9.3 (-V), U9.8 (COMMON), U$1.2 (GND)
HP_LED: J1.29, Q1.G, R6.2
MISO_P8_28: ADC2.12 (DOUT), J2.28
MISO_PRU: J1.28, U$1.5 (SDO)
MOSI_P8_29: ADC2.11 (DIN), J2.29
unnamed: D3.1 (RED), R7.2
unnamed: OP-AMP.13 (4IN-), R3.1, R4.1
unnamed: D3.4 (BLU), R8.2
unnamed: D3.3 (GRN), R9.2
unnamed: OP-AMP.10 (3IN+), R2.1, RX_PD.A
unnamed: C5.2, OP-AMP.9 (3IN-), R1.2, RX_PD.K (C)
unnamed: C1.1, OP-AMP.2 (1IN-), R11.1, RX_LED.K (C)
unnamed: LED2.A, R15.1
unnamed: OP-AMP.3 (1IN+), R12.2, RX_LED.A
unnamed: OP-AMP.6 (2IN-), R13.2, R14.2
unnamed: LED1.A, R16.1
unnamed: D2.C, Q1.D
unnamed: ADC2.1 (CH0), U9.4 (-), U9.5 (OUTPUT)
unnamed: LED2.K (C), Q2.3 (D)
unnamed: LED1.K (C), Q5.3 (D)
unnamed: LED3.A, R19.1
unnamed: D1.A, L1.1, U5.7 (SW)
unnamed: C4.1 (+), D1.C, D2.A, U5.4 (SENSE)
unnamed: C2.1, R5.2, U5.5 (ILIM)
unnamed: LED3.K (C), Q3.3 (D)
unnamed: LED4.A, R21.1
unnamed: LED4.K (C), Q4.3 (D)
P9_5: ADC2.15 (VREF), ADC2.16 (VDD), J1.5, U9.1 (V_S)
P9_6: C3.1 (+), J1.6, L1.2, U5.2 (SEL), U5.6 (VIN)
P9_7: J1.7, U$1.1 (VCC)
P9_8: ADC1.15 (VREF), ADC1.16 (VDD), J1.8, OP-AMP.4 (VCC), R15.2, R16.2, R19.2, R21.2
RGB_B: J2.46, R8.1
RGB_G: J2.45, R9.1
RGB_R: J2.43, R7.1
SCLK_P8_27: ADC2.13 (CLK), J2.27
TXLED1: J2.39, Q5.1 (G), R18.1
TXLED2: J2.40, Q2.1 (G), R17.1
TXLED3: J2.41, Q3.1 (G), R20.1
TXLED4: J2.42, Q4.1 (G), R22.1
VIN: OP-AMP.7 (2OUT), R13.1, U$1.3 (VIN)

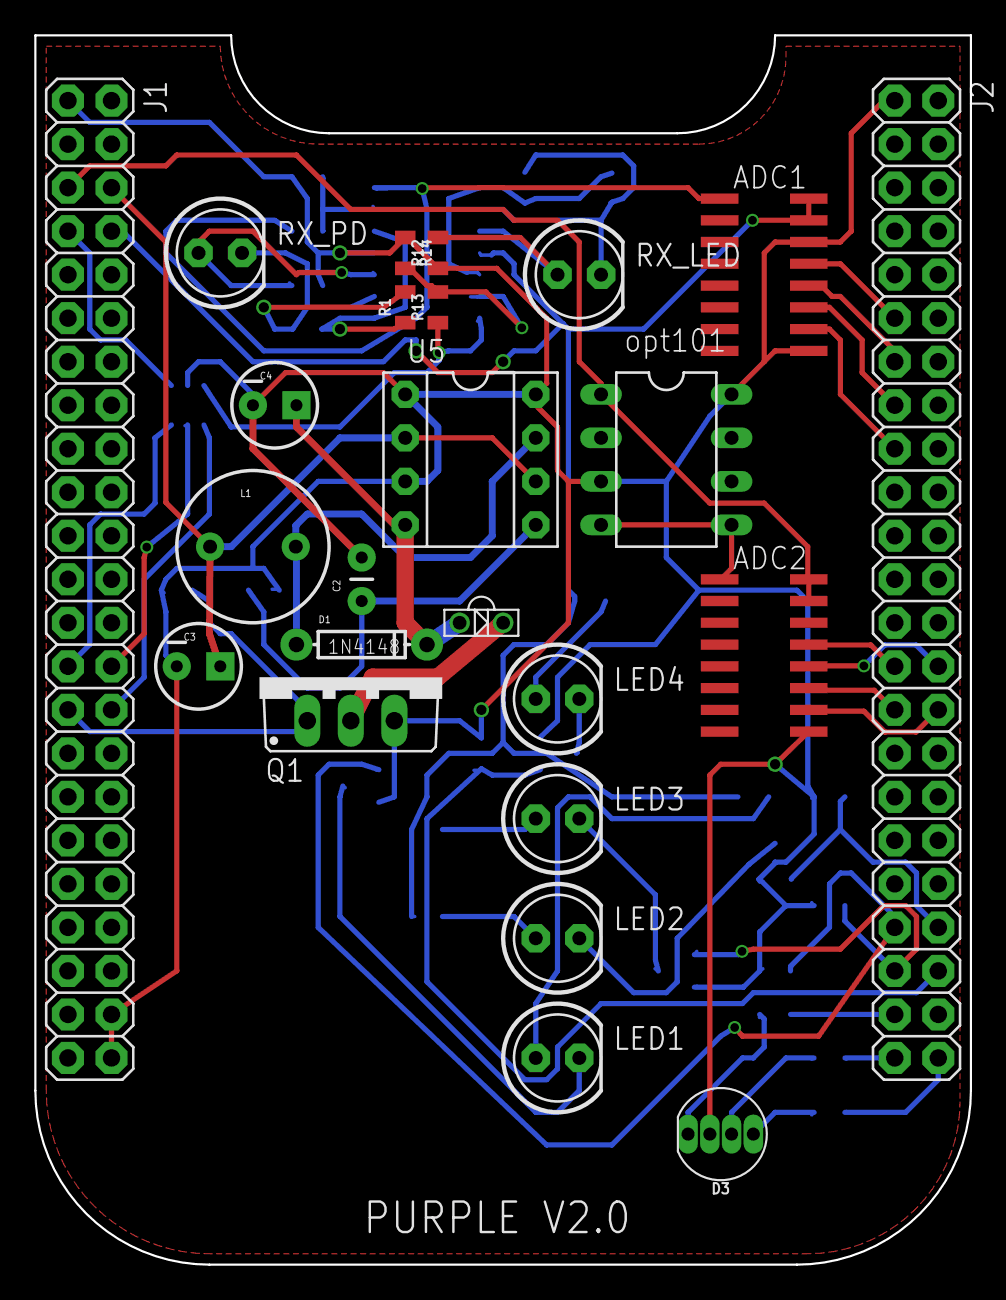
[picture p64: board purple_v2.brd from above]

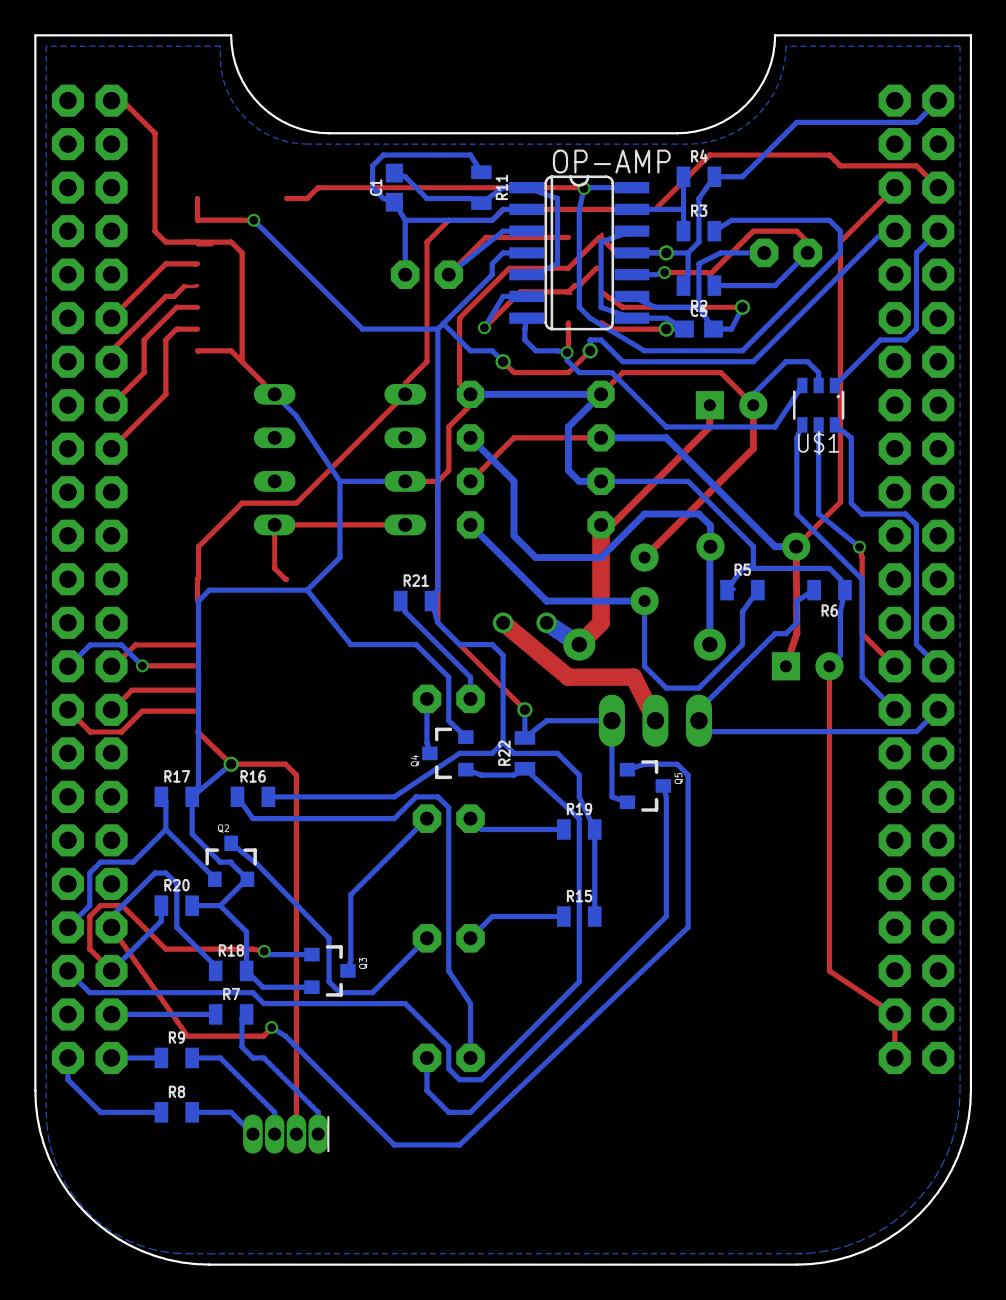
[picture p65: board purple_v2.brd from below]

Board: 2 copper layers, 54.6 x 71.8 mm, 50 parts (25 on the bottom side), 50 nets.

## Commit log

2017-03-12 added schematic and board layout...
    [purple_v2.brd, purple_v2.sch]
2017-03-12 move schematic to eagle foler
    [purple_v2.brd, purple_v2.sch]
2017-03-12 removed some file on main folder...
    [purple_v2.brd, purple_v2.sch]
2017-03-28 added bill of materials
2017-06-21 Add files via upload
    Instructions and walk-through videos for installing and running the sample network project on Beagle Bone Black for both Windows and Mac. Written by Sebastían Rivera González, Emilio Chavez Madero an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
2017-12-31 add src
    [purple_v2.brd, purple_v2.sch]
2017-12-31 add board image

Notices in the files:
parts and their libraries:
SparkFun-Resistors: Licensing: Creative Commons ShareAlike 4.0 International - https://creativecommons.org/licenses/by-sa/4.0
